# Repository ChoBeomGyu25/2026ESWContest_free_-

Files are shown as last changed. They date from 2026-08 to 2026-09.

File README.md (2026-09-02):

# 2026 ESWContest_free_옷개스트라

---

## 🏷️ Project Introduction

**옷개스트라**는 AI 기반 컴퓨터 비전과 듀얼 로봇팔을 활용하여 비정형 의류를 자동으로 인식하고 정리하는 **의류 자동 정리 로봇 시스템 「접신」**을 개발하고 있습니다.

일정한 형태를 유지하지 않는 의류의 특성을 고려하여 카메라 기반의 의류 인식과 상태 판단을 수행하고, 두 대의 로봇팔이 협업하여 의류를 파지하고 펼친 뒤 정렬 및 접기까지 수행하도록 시스템을 구성하였습니다.
이를 통해 사람이 직접 수행하던 반복적인 의류 정리 작업을 로봇과 인공지능을 이용하여 자동화하는 것을 목표로 합니다.

---

## 💡 Motivation
세탁은 **세탁기**, 건조는 **건조기**를 통해 자동화되고 있지만, 세탁이 끝난 의류를 **펼치고 정렬하여 접는 과정은 여전히 사람이 직접 수행해야 하는 대표적인 반복 가사 노동**으로 남아 있습니다. 특히 고령 인구와 맞벌이·1인 가구가 증가하면서 가사 노동에 대한 부담 역시 커지고 있으며, 반복적인 의류 정리는 시간적·신체적 부담과 일상생활의 비효율을 발생시킵니다.

기존에도 FoldiMate, Laundroid, Speedy-T 등 의류 정리를 위한 장치가 개발되었지만, **높은 가격, 긴 처리 시간, 반자동 방식, 제한적인 의류 대응 범위** 등의 한계가 존재합니다. 특히 사용자가 의류를 특정 형태로 투입하거나 사전에 정렬해야 하는 경우가 많아, 무작위로 놓이거나 구겨진 다양한 형태의 의류를 처음부터 끝까지 자동으로 처리하는 데에는 한계가 있습니다.

이에 저희는 비정형 상태로 놓인 의류를 AI기반 컴퓨터 비전으로 인식하고, 두 대의 로봇팔이 의류의 상태에 따라 직접 조작하여 **펼침·정렬·주름 및 접힘 보정·접기까지 전 과정을 수행하는 자동 의류 정리 로봇 시스템**을 제안합니다. 이를 통해 사용자의 의류 정리 부담을 줄이고, 기존 가전제품이 자동화하지 못했던 **세탁 이후의 의류 정리 과정까지 자동화**하는 것을 목표로 합니다.

---

## 🎯 Project Goal

본 프로젝트의 목표는 **무작위로 놓여 있거나 구겨진 의류의 상태를 로봇이 스스로 인식하고, 최종적으로 정돈된 형태까지 만드는 전 과정을 자동화하는 것**입니다.

의류의 형태와 위치를 AI 기반 컴퓨터 비전 통해 판단한 뒤, 두 대의 로봇팔이 협업하여 **의류 파지 → 배치 → 펼침 → 정렬 → 주름 및 접힘 보정 → 접기 → 완료 상태 판단**의 과정을 순차적으로 수행합니다.

특히 형태 변화가 큰 비정형 의류를 안정적으로 조작하기 위해 다양한 시각 인식 기술과 의류 상태에 따른 로봇 동작 판단 알고리즘을 결합하여, 여러 의류 상태에서도 유연하게 대응할 수 있는 자동 정리 시스템을 구현하는 것을 최종 목표로 합니다.

---

## 🤖 System Overview
스크린샷 2026-08-31 120610
스크린샷 2026-08-31 145607

본 시스템은 카메라 기반 비전 AI와 두 대의 로봇팔을 활용하여, 바구니에 무작위로 놓인 의류를 인식하고 펼침·정렬·보정·접기까지의 전 과정을 자동으로 수행합니다.

1. **RoArm이 바구니에서 의류를 파지**하여 폴딩 플레이트 위로 이동
2. **카메라 영상과 ArUco Marker / Checkerboard**를 이용하여 영상 좌표를 실제 로봇 작업 좌표계로 변환
3. **Segmentation 및 Pose 모델**을 통해 의류의 영역과 주요 특징점을 인식
4. 두 대의 로봇팔을 이용하여 **공중 Spread 및 초기 정렬 동작**을 수행
5. **Fallback Mask, Wrinkle Heatmap, UniDepth** 등을 이용하여 의류의 구김·접힘 및 현재 상태를 분석
6. 분석된 의류 상태를 기반으로 **펼침·당기기·회전 등 필요한 보정 동작**을 선택하여 반복 수행
7. 의류가 충분히 평활화되고 정렬되면 **Finish 상태로 판단**하고 폴딩 플레이트를 구동하여 의류를 접음
8. 접힌 의류를 배출한 뒤 로봇이 초기 위치로 복귀하여 **다음 의류 정리 작업을 준비**

---

## ⚙️ Hardware
스크린샷 2026-08-31 145738
Hardware 구성 및 기능
스크린샷 2026-08-31 145722

---

## 🧠 Software / AI
상의 주요 함수별 기능
하의 주요 함수별 기능
Jerber
Application

---

## 👕 Clothing Manipulation Process
스크린샷 2026-08-31 161525
스크린샷 2026-08-31 161535
스크린샷 2026-08-31 161541
스크린샷 2026-08-31 161547

---

## 📈Expected Effects & Development
스크린샷 2026-08-31 163309

본 시스템은 세탁 이후 사람이 직접 수행해야 했던 **의류 펼침·정렬·주름 및 접힘 보정·접기 과정을 자동화**함으로써 반복적인 가사 노동에 소요되는 시간과 신체적 부담을 줄이는 것을 목표로 합니다. 특히 일반적인 의류 정리에 평균 10~30분 정도가 소요되는 점을 고려할 때, 사용자의 개입을 최소화하여 의류 정리 과정을 자동으로 수행할 수 있다면 일상생활에서 실질적인 시간 절감 효과를 기대할 수 있습니다. 또한 자체 진행한 설문조사에서는 총 145명의 응답자 중 **111명, 약 76.6%가 '자동으로 옷을 개어주는 로봇'의 출시 시 구매 의향에 긍정적인 응답**을 보여, 자동 의류 정리에 대한 실제 사용자 수요와 활용 가능성도 확인하였습니다. 향후 세탁기와 건조기뿐만 아니라 의류 보관 시스템까지 연계한다면 **세탁 → 건조 → 정리 → 보관으로 이어지는 통합 스마트 홈 의류 관리 시스템**으로 발전할 수 있습니다.

본 기술은 가정용 스마트 홈을 넘어 **의류 유통·전자상거래 및 물류 산업으로의 확장 가능성**도 가지고 있습니다. 온라인 의류 판매 시장이 성장하면서 반품된 상품의 상태 확인, 펼침, 정렬, 재포장 등의 반복 작업 역시 증가하고 있으며, 이러한 과정에 비정형 의류 인식과 로봇 조작 기술을 적용하면 작업 효율과 공간 활용도를 높일 수 있습니다. 특히 다양한 형태로 놓인 의류를 AI 기반 컴퓨터 비전이 인식하고 상태에 따라 필요한 조작 동작을 선택하는 기술을 고도화할 경우, 패션 물류센터나 대형 세탁·정리 시설에서 반복적으로 수행되는 단순 작업을 자동화할 수 있습니다. 이를 통해 제한된 인력을 반복 작업에 투입하는 대신 **품질 관리, 고객 대응, 시스템 운영 등 보다 높은 부가가치를 갖는 업무에 집중**시킬 수 있으며, 장기적으로는 인력난 대응과 운영 비용 절감에도 기여할 수 있습니다. 최종적으로 본 프로젝트는 단순히 옷을 접는 하나의 가전제품을 넘어, **비정형 섬유 제품을 스스로 인식하고 판단하여 조작할 수 있는 지능형 로봇 자동화 플랫폼**으로 발전하는 것을 목표로 합니다.

---

## ⚙️ Environment

| Category | Environment |
|---|---|
| 💻 **Main Processor** |  |
| 🔧 **Sub Controller** |  |
| 🐧 **OS** |  |
| 📦 **Container** |  |
| 💻 **Programming Language** |  |
| 🤖 **Robot Platform** |   |
| 🔌 **Communication** |  |
| 📷 **Camera** |  |
| 📐 **Vision Calibration** |  |
| 🧠 **AI Framework** |   |
| 👕 **Garment Perception** |   |
| ⚡ **Inference Engine** |  |
| 🎮 **GPU Runtime** |  |
| 📏 **Depth Estimation** |  |
| 📊 **Learning / Prediction** |  |
| 🛠️ **Libraries & Tools** |    |

---

## 👥 Team Members

- 조범규
- 유채린
- 임혜강
- 정유환
- 조승진

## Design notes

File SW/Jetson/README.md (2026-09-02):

# Jetson 소프트웨어

이 디렉터리는 팀 **옷개스트라**의 자동 의류 정리 로봇 시스템 **「접신」**에서 NVIDIA Jetson Orin Nano를 기반으로 실행되는 **AI 기반 컴퓨터 비전, 의류 상태 분석, 조작 계획 및 듀얼 로봇팔 제어 소프트웨어**를 포함합니다.

Jetson은 상부 ELP OV2710 카메라 영상을 입력받아 의류의 위치와 형상을 인식하고, 카메라 픽셀 좌표를 실제 폴딩 보드 및 로봇 작업공간 좌표로 변환한 뒤 상의와 하의 상태에 맞는 조작 동작을 수행하는 핵심 연산 장치입니다.

현재 저장소에서는 실제 로봇에서 검증된 실행 코드와 학습 기반 동작 판단 모델을 함께 관리합니다.

---

# 1. 디렉터리 구성

    SW/Jetson/
    ├── README.md
    │
    ├── preprocessing/
    │   ├── README.md
    │   ├── upper/
    │   │   ├── README.md
    │   │   ├── run_upper.py
    │   │   └── ...
    │   │
    │   └── lower/
    │       ├── README.md
    │       ├── run_lower.py
    │       ├── dual/
    │       │   ├── step_e49_bottom_perception.py
    │       │   ├── step_e62_bottom_perception.py
    │       │   ├── step_d25_v2.py
    │       │   └── undistort/
    │       │       ├── bottom_vla-38_submission_full_auto.py
    │       │       ├── main-33_submission_runtime.py
    │       │       ├── 50-1.py
    │       │       ├── 54-3.py
    │       │       ├── 55-5.py
    │       │       ├── 58-3.py
    │       │       ├── 60-15.py
    │       │       ├── align-11.py
    │       │       └── ...
    │       └── outputs/
    │
    ├── common/
    │   ├── camera/
    │   └── calibration/
    │
    ├── models/
    │   ├── segmentation/
    │   └── pose/
    │       ├── upper/
    │       └── lower/
    │
    ├── policy/
    │
    └── runtime/

---

# 2. Jetson의 역할

Jetson 소프트웨어의 주요 기능은 다음과 같습니다.

1. ELP OV2710 카메라 영상 획득
2. 카메라 보정 및 렌즈 왜곡 보정
3. YOLO 기반 의류 세그멘테이션
4. 상의 / 하의 포즈 및 특징점 추론
5. 의류 마스크 및 윤곽선 분석
6. 키포인트 / 랜드마크 분석
7. 의류 방향 및 위치 분석
8. 접힘 / 주름 및 의류 형상 분석
9. 카메라 픽셀 좌표를 폴딩 보드 / 로봇 좌표로 변환
10. 로봇 파지점 계산
11. 조작 계획 생성
12. 듀얼 로봇팔 제어
13. 조작 후 새로운 의류 상태 재관찰
14. 학습 모델 기반 다음 조작 동작 결정
15. 접기 준비 완료 종료조건 판단
---

# 3. 전처리 및 실행 코드 (`preprocessing/`)

`preprocessing/`은 상의와 하의의 실제 의류 인식 및 로봇 조작 실행 코드를 관리합니다.

    SW/Jetson/preprocessing/
    ├── upper/
    └── lower/

상의와 하의는 구조와 조작 방법이 서로 다르기 때문에 각각 실제 로봇에서 검증된 실행 구조를 유지합니다.

단순한 소스 통합이나 중복 제거보다 **실제 로봇에서 검증된 의존성과 실행 재현성**을 우선합니다.

---

# 4. 현재 상의 실행 코드

현재 상의 메인 실행 코드는 GitHub 저장소에 포함되어 있습니다.

경로:

    SW/Jetson/preprocessing/upper/

실행 파일:

    SW/Jetson/preprocessing/upper/run_upper.py

현재 상의 시스템은 초기 의류 배치부터 **학습 모델 기반 동작 판단, 반복 조작 및 FINISH 판단까지 자동으로 수행하는 구조**로 구성되어 있습니다.

전체 흐름:

    바구니 의류 파지
            ↓
    폴딩 보드 위 이동
            ↓
    의류 내려놓기
            ↓
    YOLO 세그멘테이션 + YOLO 포즈
            ↓
    의류 상태 분석
            ↓
    커스텀 동작 결정 모델
            ↓
    안전한 조작 계획 생성
            ↓
    듀얼 로봇팔 동작 수행
            ↓
    Standby 복귀
            ↓
    새로운 의류 상태 재관찰
            ↓
    다음 동작 자동 판단
            ↓
    반복 조작 / FINISH

의존성 확인:

    python3 SW/Jetson/preprocessing/upper/run_upper.py --paths-only

실제 로봇 자동 실행:

    python3 SW/Jetson/preprocessing/upper/run_upper.py --physical-auto

`--physical-auto`는 실제 듀얼 로봇팔을 사용하는 상의 자동 정리 실행 옵션입니다.

---

# 5. 상의 학습 기반 자동 조작

상의에는 **현재 의류 상태를 보고 다음 조작 동작을 결정하는 커스텀 학습 모델**이 적용되어 있습니다.

의류 영상과 세그멘테이션, 포즈, 주름 및 위치 분석 결과를 이용하여 현재 상태를 표현하고, **Board+State v2 커스텀 모델**이 다음 동작을 우선 판단합니다. Jetson에서는 TensorRT 엔진으로 추론합니다.

현재 판단 구조:

    카메라 관찰
            ↓
    세그멘테이션 / 포즈 / 상태 분석
            ↓
    Board+State v2 모델
            ↓
    다음 조작 동작 후보 결정
            ↓
    신뢰도 및 적용 조건 확인
       /                    \
    통과                     미통과
     ↓                        ↓
    모델 판단 사용        규칙 기반 상태 판단 로직 사용
       \                    /
        ↓
    최종 조작 계획 및 안전 검사
            ↓
    로봇 실행
            ↓
    재관찰
            ↓
    다음 동작 자동 판단

현재 커스텀 모델은 7개 동작 클래스를 학습했으며, 제출용 실행 코드에서는 신뢰도와 margin 조건을 만족한 `CENTER`, `SPREAD`, `ROTATE`, `FINISH` 판단을 우선 직접 사용합니다. 그 외 경우에는 규칙 기반 상태 판단 로직으로 넘어갑니다.

즉, 현재 상의 코드는 **커스텀 모델을 우선 사용하여 동작을 판단하고, 모델 판단을 직접 채택하기 어려운 경우 규칙 기반 상태 판단 로직을 보조 경로로 사용**합니다.

실제 파지점과 이동 경로는 기존 검증된 조작 계획 및 안전 검사 로직을 통해 최종 결정됩니다.

조작이 끝나면 로봇팔이 대기 위치로 복귀한 뒤 새로운 영상을 다시 관찰하고 필요한 동작을 반복합니다. `FINISH`가 선택되면 해당 의류의 자동 조작 루프를 종료합니다.

---

# 6. 현재 하의 실행 코드

현재 하의 실행 코드는 **V38 Full-Auto 구조**로 구성되어 있으며 GitHub 저장소에 포함되어 있습니다.

실행 진입점:

    SW/Jetson/preprocessing/lower/run_lower.py

하의 Full-Auto 상위 실행 코드:

    SW/Jetson/preprocessing/lower/dual/undistort/bottom_vla-38_submission_full_auto.py

하위 실행 연결 코드:

    SW/Jetson/preprocessing/lower/dual/undistort/bottom_vla-23_submission_runtime.py
    SW/Jetson/preprocessing/lower/dual/undistort/main-33_submission_runtime.py

주요 인식 및 조작 관련 모듈:

    SW/Jetson/preprocessing/lower/dual/undistort/50-1.py
    SW/Jetson/preprocessing/lower/dual/undistort/54-3.py
    SW/Jetson/preprocessing/lower/dual/undistort/55-5.py
    SW/Jetson/preprocessing/lower/dual/undistort/58-3.py
    SW/Jetson/preprocessing/lower/dual/undistort/60-15.py
    SW/Jetson/preprocessing/lower/dual/undistort/align-11.py
    SW/Jetson/preprocessing/lower/dual/undistort/step_e49_bottom_perception.py
    SW/Jetson/preprocessing/lower/dual/undistort/step_e62_bottom_perception.py
    SW/Jetson/preprocessing/lower/dual/undistort/step_d25_v2.py

현재 하의는 카메라와 AI 모델을 이용하여 의류 상태를 인식한 뒤, 현재 상태에 맞는 의미 동작을 자동으로 선택하고 조작 후 다시 관찰하는 **반복형 자동 조작 구조**를 사용합니다.

주요 의미 동작:

- `BASKET_GRASP`
- `POSITION_ADJUST`
- `OUTER_PULL`
- `PRESS_SWEEP`
- `WAIST_PULL_LAYDOWN`
- `ALIGN`
- `FINISH`

하의 인식에는 의류 세그멘테이션, 하의 포즈, 마스크 기하 정보, 윤곽선, 허리선, 가랑이, 다리와 밑단, 접힘 및 주름, 정렬 상태 등의 정보를 함께 사용합니다.

---

# 7. 하의 자동 동작 판단

V38에서는 기존의 사용자 수동 동작 선택을 중심으로 한 구조에서 벗어나, 현재 관찰된 의류 상태를 기반으로 다음 의미 동작을 자동으로 선택합니다.

기본 판단 흐름:

    카메라 관찰
        ↓
    의류 세그멘테이션 / 하의 포즈 추론
        ↓
    의류 형상 및 상태 분석
        ↓
    AUTO-JUDGE
        ↓
    의미 동작 자동 선택
        ↓
    조작 계획 생성 및 안전 검사
        ↓
    로봇 조작

자동 판단 결과는 기존에 검증된 조작 코드와 연결되어 실제 파지점, 이동 경로 및 로봇 동작을 생성합니다.

즉 인식 및 상태 판단 계층과 실제 로봇 조작 계층을 분리하면서, 상위 자동 판단 결과를 기존 조작 코드에 전달하는 구조입니다.

---

# 8. 하의 Full-Auto 반복 조작 구조

V38 Full-Auto는 한 번의 상태 판단만 수행하는 것이 아니라 조작 후 새로운 상태를 다시 관찰하고 다음 동작을 판단하는 반복 구조를 사용합니다.

전체 흐름:

    X 입력으로 Full-Auto 시작
        ↓
    BASKET_GRASP
        ↓
    POSITION_ADJUST
        ↓
    새로운 의류 상태 관찰
        ↓
    AUTO-JUDGE
        ↓
    의미 동작 자동 선택
        ↓
    로봇 조작
        ↓
    새로운 의류 상태 재관찰
        ↓
    상태 재평가
        ↓
    다음 동작 자동 선택
        ↓
    반복 또는 FINISH

초기 바구니 파지 이후에는 의류를 작업 영역에 배치하고 위치를 보정한 뒤, 매 조작마다 새로운 카메라 관찰 결과를 이용하여 다음 동작을 다시 판단합니다.

이를 통해 이전 조작 이전의 상태를 계속 사용하는 것이 아니라 **조작 결과가 반영된 새로운 의류 상태를 기준으로 다음 행동을 결정**합니다.

---

# 9. 하의 종료조건 판단

하의 자동화는 단순히 정해진 횟수만큼 조작한 뒤 종료하는 방식이 아니라, 현재 의류 상태를 재평가하여 추가 조작이 필요한지 판단합니다.

상태 판단에는 다음과 같은 정보를 활용합니다.

- 의류가 충분히 펼쳐졌는지 여부
- 큰 접힘 및 주름 상태
- 허리선 구조
- 가랑이 및 다리 구조
- 양쪽 밑단 상태
- 의류 중심 위치
- 폴딩 보드 기준 정렬 상태
- 추가 위치 보정 또는 펼침 동작의 필요 여부

자동 판단 결과 추가 조작이 필요하면 다음 의미 동작을 선택하여 반복하고, 접기 단계로 진행할 수 있는 상태라고 판단하면 `FINISH`로 종료합니다.

반복 구조:

    의류 관찰
        ↓
    상태 분석
        ↓
    AUTO-JUDGE
        ↓
    추가 조작 필요?
       /          \
     YES          NO
      ↓            ↓
    동작 선택      FINISH
      ↓
    로봇 조작
      ↓
    재관찰
      ↓
    반복

---

# 10. 상의 / 하의 최종 통합 방향

상의와 하의는 모두 **의류를 관찰하고, 현재 상태를 판단하고, 필요한 동작을 수행한 뒤 다시 관찰하는 폐루프(Closed-loop) 구조**를 지향합니다.

    의류 입력
        ↓
    의류 인식
        ↓
    의류 상태 분석
        ↓
    동작 판단
        ↓
    두 로봇팔 조작
        ↓
    재관찰
        ↓
    상태 재평가
        ↓
    추가 동작 / 종료 판단
        ↓
    접기 준비 완료
        ↓
    폴딩 보드

상의는 Board+State v2 학습 모델과 규칙 기반 상태 판단을 결합한 자동 조작 모듈을 사용하며, 하의는 V38 Full-Auto 정책을 통해 의미 동작을 자동 선택하고 재관찰을 반복하는 구조를 사용합니다.

예선 제출에서는 상의와 하의의 각 실행 구조를 독립적으로 관리하며, 이후 전체 시스템에서는 의류 종류에 따라 해당 처리 흐름을 선택한 뒤 최종 폴딩 단계로 연결하는 구조를 목표로 합니다.

---

# 11. 모델

TensorRT 기반 AI 모델은 다음 디렉터리에서 관리합니다.

    SW/Jetson/models/

현재 의류 인식 모델:

    models/
    ├── segmentation/
    │   └── kfashion_yolo26s_seg3_e100_best.engine
    │
    └── pose/
        ├── upper/
        │   └── tshirt_pose_yolo26m_synth_artf_board_v1_best.engine
        │
        └── lower/
            └── bottom_pose8_yolo26m_robot_beige_retrain_all_v2.engine

상의에서는 의류 인식 모델과 별도로 **다음 조작 동작을 판단하기 위한 Board+State v2 커스텀 모델**을 사용합니다.

주요 파일:

    top_board_state_v2_fp32.engine
    state_normalization.npz

- `top_board_state_v2_fp32.engine` : Jetson에서 사용하는 TensorRT 동작 결정 모델
- `state_normalization.npz` : 모델 입력에 사용되는 상태값 정규화 정보

Jetson의 실제 동작 결정 추론에서는 TensorRT 엔진과 `state_normalization.npz`를 사용합니다.

자세한 내용:

    SW/Jetson/models/README.md
---

# 12. 공통 보정 리소스

`common/`은 카메라 좌표와 실제 폴딩 보드 / 로봇 작업공간을 연결하기 위한 카메라 및 보정 리소스를 포함합니다.

    SW/Jetson/common/
    ├── camera/
    └── calibration/

주요 리소스:

- ELP OV2710 카메라 왜곡 보정
- 카메라 내부 파라미터 보정
- 듀얼 로봇팔 / 폴딩 보드 설정
- 바구니 ARM2 Affine 보정
- 폴딩 보드 Homography

---

## Homography 주의사항

상의 공통 실행 코드와 하의 실행 코드에는 동일한 이름의 Homography 파일이 존재하지만 서로 다른 좌표계 처리 요구사항을 가집니다.

상의 / 공통:

    SW/Jetson/common/calibration/
    └── elp_ov2710_folding_board_homography_cache.json

하의 전용:

    SW/Jetson/preprocessing/lower/dual/undistort/
    └── elp_ov2710_folding_board_homography_cache.json

하의 버전은 원본 / 보정 프레임 기하 정보를 구분하기 위해 `H`, `raw_H`, `camera_geometry`, `schema_version` 정보를 사용합니다.

따라서 두 Homography 파일을 서로 덮어쓰거나 임의로 하나로 통합하면 안 됩니다.

자세한 내용:

    SW/Jetson/common/README.md
---

# 13. 동작 판단 정책

`policy/`는 의류 상태와 로봇 조작 동작 사이의 상위 판단 구조를 설명합니다.

### 상의

- YOLO 세그멘테이션 / 포즈 기반 의류 상태 인식
- Board+State v2 커스텀 모델 기반 동작 판단
- 학습 모델 판단을 우선 사용하고 필요한 경우 규칙 기반 상태 판단으로 보완
- 기존 조작 계획 및 안전 검사 로직을 이용하여 실제 로봇 동작 생성
- 조작 후 새로운 의류 상태를 재관찰
- 다음 동작을 다시 판단하는 반복 구조
- `FINISH` 판단 시 해당 의류의 자동 조작 종료

### 하의

- V38 Full-Auto 기반 자동 의미 동작 선택
- 바구니 파지 후 `POSITION_ADJUST`를 수행하여 작업 영역의 초기 상태 보정
- 카메라, 세그멘테이션, 하의 포즈 및 형상 분석 결과를 이용한 상태 판단
- `AUTO-JUDGE`를 통한 다음 의미 동작 자동 선택
- 선택된 동작을 기존 검증된 조작 코드와 연결
- 각 조작 이후 새로운 의류 상태를 재관찰
- 재관찰 결과를 이용하여 다음 동작을 반복 판단
- 접기 준비 상태가 충족되면 `FINISH`로 해당 의류 조작 종료

상의와 하의 모두 인식 결과를 한 번만 사용하는 방식이 아니라, **조작 → 재관찰 → 상태 재평가 → 다음 동작 판단**을 반복하는 폐루프 구조를 최종 동작 정책으로 사용합니다.

---

# 14. 실행 구조

「접신」의 실제 실행 구조는 **의류 인식 → 동작 판단 → 로봇 실행 → 재관찰 → 종료 판단**의 흐름으로 구성됩니다.

현재 실제 검증된 소스 코드는 다음 디렉터리에 위치합니다.

상의:

    SW/Jetson/preprocessing/upper/

하의:

    SW/Jetson/preprocessing/lower/

검증된 기존 소스 의존성과 동적 소스 로딩 구조를 유지하기 위해 실행 소스 자체를 `runtime/`로 임의 이동하지 않습니다.

`runtime/` 디렉터리는 전체 실행 구조와 상·하의 실행 관계를 설명하는 계층으로 사용합니다.

---

# 15. 실행 환경

현재 Jetson 실행 검증 환경:

- 주 프로세서: NVIDIA Jetson Orin Nano
- 운영체제: Ubuntu 22.04.3
- Python: 3.10.12
- TensorRT: 10.7.0
- OpenCV: 4.11.0
- NumPy: 1.26.4
- PyTorch: 2.10.0
- CUDA 런타임: 12.6 (PyTorch)
- Ultralytics: 8.4.45
- XGBoost: 3.2.0
- Docker: 29.7.2
- 로봇: Dual RoArm M2-S
- 카메라: ELP OV2710
- 카메라 해상도: 1280 × 720
- 통신: USB 시리얼

로봇 장치:

    ARM1: /dev/roarm_1
    ARM2: /dev/roarm_2

카메라 장치:

    /dev/video0

---

# 16. 최종 목표

Jetson 소프트웨어의 최종 목표는 다음과 같은 **폐루프 자동 의류 조작 시스템**을 구현하는 것입니다.

    카메라
      ↓
    의류 인식
      ↓
    의류 상태 분석
      ↓
    동작 판단
      ↓
    Dual RoArm 조작
      ↓
    재관찰
      ↓
    추가 동작 / 종료 판단
      ↓
    접기 준비 완료
      ↓
    폴딩 보드

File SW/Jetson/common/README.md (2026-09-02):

# 공통 리소스

이 디렉터리는 자동 의류 정리 로봇 시스템 **「접신」**의 Jetson 실행 환경에서 사용하는 공통 카메라 및 보정 리소스를 관리합니다.

카메라 영상에서 검출한 의류의 위치와 특징점을 실제 폴딩 보드 및 Dual RoArm M2-S 작업 좌표로 연결하기 위해 카메라 보정, Homography, Affine 변환 및 로봇 / 보드 설정을 사용합니다.

다만 실제 제출 실행 환경에서는 재현성과 기존 의존성 구조 보존을 위해 모든 파일을 상의와 하의가 동일한 위치에서 직접 참조하는 것은 아닙니다.

특히 하의 실행 코드는 일부 카메라 리소스와 하의 전용 Homography를 `preprocessing/lower/` 내부에 별도로 유지합니다.

---

# 1. 디렉터리 구성

    SW/Jetson/common/
    ├── README.md
    │
    ├── camera/
    │   ├── camera_undistort.py
    │   ├── elp_ov2710_1280x720_calibration.npz
    │   └── elp_ov2710_camera_controls.json
    │
    └── calibration/
        ├── dual_roarm_folding_board_config.json
        ├── basket_arm2_5point_affine.json
        └── elp_ov2710_folding_board_homography_cache.json

---

# 2. 카메라 리소스

## camera_undistort.py

경로:

    SW/Jetson/common/camera/camera_undistort.py

ELP OV2710 광각 카메라의 렌즈 왜곡을 보정하기 위한 공통 모듈입니다.

카메라 보정 정보를 이용하여 영상 왜곡을 보정하고, 이후 수행되는 세그멘테이션, 포즈 추론 및 기하 계산에서 픽셀 위치의 오차를 줄이는 데 사용합니다.

상의 제출 실행 코드에서는 해당 공통 카메라 모듈을 의존 파일로 사용합니다.

하의 실행 코드에는 동일한 카메라 보정 모듈의 검증된 로컬 복사본이 다음 위치에 존재합니다.

    SW/Jetson/preprocessing/lower/dual/undistort/
    └── camera_undistort.py

하의 로컬 복사본은 공통 버전과 파일 내용이 동일함을 SHA-256으로 검증했지만, 기존 하의 동적 소스 로딩 구조와 실행 재현성을 보존하기 위해 의도적으로 중복 유지합니다.

따라서 단순한 중복 제거를 목적으로 하의 로컬 복사본을 삭제하거나 import 구조를 변경하지 않는 것을 권장합니다.

---

## elp_ov2710_1280x720_calibration.npz

경로:

    SW/Jetson/common/camera/
    └── elp_ov2710_1280x720_calibration.npz

ELP OV2710 카메라의 1280 × 720 해상도 보정 데이터를 저장합니다.

카메라 내부 파라미터와 렌즈 왜곡 보정에 필요한 정보를 포함하며 `camera_undistort.py`와 함께 사용합니다.

현재 제출 실행 코드는 1280 × 720 카메라 입력을 기준으로 구성되어 있습니다.

하의 실행 코드에도 동일한 카메라 보정 NPZ의 검증된 로컬 복사본이 존재합니다.

    SW/Jetson/preprocessing/lower/dual/undistort/
    └── elp_ov2710_1280x720_calibration.npz

두 파일은 SHA-256 기준으로 동일하지만 하의 실행 코드의 검증된 소스 구조를 유지하기 위해 로컬 복사본을 보존합니다.

---

## elp_ov2710_camera_controls.json

경로:

    SW/Jetson/common/camera/
    └── elp_ov2710_camera_controls.json

ELP OV2710 카메라의 촬영 조건을 실행 환경에서 동일하게 재현하기 위한 **V4L2 카메라 제어 설정 파일**입니다.

이 파일은 카메라 내부 파라미터나 렌즈 왜곡 정보를 저장하는 보정 파일이 아니라, `/dev/video0`에 적용할 노출, 게인, 전원 주파수 및 화이트밸런스 값을 저장합니다.

현재 저장된 설정:

    auto_exposure: 1
    exposure_time_absolute: 151
    gain: 0
    power_line_frequency: 2
    white_balance_automatic: 0
    white_balance_temperature: 4600

상의 신규 자동화 실행기:

    SW/Jetson/preprocessing/upper/automation/run_upper_automation.py

는 실행 시 이 파일을 `--camera-controls-json` 인자로 전달합니다.

상의 자동화 코드에서는 카메라 초기화 과정에서 해당 설정을 `/dev/video0`에 적용한 뒤 카메라 보정, 세그멘테이션, 포즈 추론 및 의류 상태 판단을 수행합니다.

따라서 이 파일은 **카메라 영상의 밝기와 색 조건을 재현하여 비전 추론 환경을 일정하게 유지하기 위한 실행 의존 파일**입니다.

하의에도 동일한 카메라 설정의 검증된 로컬 복사본이 다음 위치에 존재합니다.

    SW/Jetson/preprocessing/lower/dual/
    └── elp_ov2710_camera_controls.json

공통 파일과 하의 로컬 파일은 SHA-256 기준으로 동일하지만, 하의 V38의 기존 실행 의존성 구조를 유지하기 위해 하의 로컬 복사본을 삭제하거나 공통 경로로 임의 통합하지 않습니다.

검증된 SHA-256:

    222e1b6826666a80918a271ea3c29dff62c77ecc94002dc4027a185e075bb206

---

# 3. 보정 리소스

## dual_roarm_folding_board_config.json

경로:

    SW/Jetson/common/calibration/
    └── dual_roarm_folding_board_config.json

Dual RoArm M2-S와 Folding Board 환경에서 사용하는 공통 Configuration입니다.

Robot Manipulation과 Board 기준 Geometry 계산에 필요한 설정 정보를 Runtime에서 참조합니다.

상의 및 하의 저장소 실행기에서 공통 보정 리소스로 사용합니다.

---

## basket_arm2_5point_affine.json

경로:

    SW/Jetson/common/calibration/
    └── basket_arm2_5point_affine.json

ARM2가 Basket 영역의 의류를 파지할 때 사용하는 Affine Calibration 데이터입니다.

Camera Image에서 얻은 Basket 영역의 Pixel Coordinate를 ARM2가 실제로 접근할 수 있는 Robot Workspace Coordinate로 변환하는 데 사용합니다.

개념적인 좌표 변환은 다음과 같습니다.

    Basket Camera Pixel
            ↓
    5-Point Affine Calibration
            ↓
    ARM2 Workspace Coordinate
            ↓
    Basket Grasp

상의 및 하의 실행 코드에서 저장소 상대경로 기반 공통 보정 리소스로 사용합니다.

---

# 4. 공통 Homography

경로:

    SW/Jetson/common/calibration/
    └── elp_ov2710_folding_board_homography_cache.json

이 파일은 Folding Board 영역의 Camera Pixel Coordinate와 실제 Board Coordinate 사이의 관계를 나타내는 Homography Calibration입니다.

현재 Common Directory의 Homography는 실제 상의 통합 Runtime에서 검증된 **H-only Calibration**입니다.

파일 특성:

    Size: 282 bytes
    JSON Key: H

검증된 SHA-256:

    282ebbcb635068031f0c238b7ab1b7c715819771ced86d614311ff875a13f397

상의 Runtime에서는 Segmentation 및 Pose Estimation으로 얻은 Pixel 위치를 실제 Folding Board 좌표로 변환하여 Robot Grasp Point 및 이동 Target을 계산하는 데 사용합니다.

---

# 5. 매우 중요: 하의 전용 Homography와의 차이

하의 Runtime에는 Common Homography와 **동일한 파일명을 가진 별도의 Homography**가 존재합니다.

하의 전용 경로:

    SW/Jetson/preprocessing/lower/dual/undistort/
    └── elp_ov2710_folding_board_homography_cache.json

이 파일은 Common Directory의 H-only Homography와 동일한 파일이 아닙니다.

---

## 공통 / 상의 Homography

경로:

    SW/Jetson/common/calibration/
    └── elp_ov2710_folding_board_homography_cache.json

특성:

    Size: 282 bytes
    Keys:
        H

SHA-256:

    282ebbcb635068031f0c238b7ab1b7c715819771ced86d614311ff875a13f397

---

## 하의 전용 Homography

경로:

    SW/Jetson/preprocessing/lower/dual/undistort/
    └── elp_ov2710_folding_board_homography_cache.json

특성:

    Size: 1040 bytes

    Keys:
        H
        raw_H
        camera_geometry
        schema_version

SHA-256:

    0a59a7a25f09af2edd235f5ee881ec48c9c52736200f7e91ed69ab1726b26a45

하의 `main-33_submission_runtime.py` Runtime은 Raw Frame과 Corrected Frame의 Geometry를 구분하여 처리하므로 `raw_H`와 `camera_geometry` 정보를 포함한 Lower 전용 Homography가 필요합니다.

---

## 절대 통합하지 않는 이유

두 Homography 파일은 파일명이 같지만 다음과 같이 Runtime 요구사항이 다릅니다.

    Common / Upper
        ↓
    H-only Geometry
        ↓
    상의 실행 코드

    Lower
        ↓
    H + raw_H + camera_geometry
        ↓
    Raw / Corrected Frame Geometry 분리
        ↓
    하의 실행 코드

따라서 다음 작업을 수행하면 안 됩니다.

- Lower Homography를 Common Homography 위에 덮어쓰기
- Common Homography를 Lower Homography 위에 덮어쓰기
- 파일명이 같다는 이유로 하나의 파일로 통합
- 하의 실행 코드가 공통 Homography 하나만 사용하도록 임의 수정
- 검증 없이 Homography JSON 구조 변경

**동일한 파일명은 동일한 Runtime Artifact라는 의미가 아닙니다.**

GitHub 제출본에서는 두 Calibration을 각각의 검증된 위치에 그대로 유지합니다.

---

# 6. 기본 좌표 변환 흐름

Folding Board 위 의류의 기본 좌표 변환은 다음과 같습니다.

    ELP OV2710 Camera
            ↓
    Camera Calibration
            ↓
    Lens Undistortion
            ↓
    Segmentation / Pose Estimation
            ↓
    Pixel Coordinate
            ↓
    Homography
            ↓
    Folding Board Coordinate
            ↓
    Robot Manipulation Target

Basket 영역에서는 별도의 Affine Calibration을 사용합니다.

    ELP OV2710 Camera
            ↓
    Basket Pixel Coordinate
            ↓
    basket_arm2_5point_affine.json
            ↓
    ARM2 Workspace Coordinate
            ↓
    Basket Grasp

---

# 7. Homography란?

Homography는 Camera Image Plane과 Folding Board와 같은 실제 평면 사이의 Projective Coordinate Relationship을 표현합니다.

Camera 영상에서 검출한 특정 Pixel을 Homography Matrix로 변환하여 Board 위 실제 위치에 대응시킴으로써 Vision Perception 결과를 Robot Manipulation 좌표와 연결합니다.

본 프로젝트에서는 Homography를 다음 작업에 활용합니다.

- Garment Grasp Point 좌표 변환
- Folding Board 기준 의류 위치 계산
- Robot 이동 Target 계산
- Garment Alignment
- Manipulation Planning
- Board Geometry 기준 Position Evaluation

---

# 8. Affine 보정

Basket 영역은 Folding Board와 다른 작업 공간에 존재하므로 별도의 ARM2 Affine Calibration을 사용합니다.

`basket_arm2_5point_affine.json`을 이용하여 Basket Camera Pixel Coordinate를 ARM2 Workspace Coordinate로 변환합니다.

이를 통해 Camera에서 인식한 Basket 내 의류 위치와 실제 ARM2 Grasp 위치를 연결합니다.

---

# 9. 실행 코드별 리소스 사용 구조

## 상의 실행 코드

주요 공통 의존 파일:

    SW/Jetson/common/camera/camera_undistort.py
    SW/Jetson/common/camera/elp_ov2710_1280x720_calibration.npz
    SW/Jetson/common/camera/elp_ov2710_camera_controls.json

    SW/Jetson/common/calibration/
    ├── dual_roarm_folding_board_config.json
    ├── basket_arm2_5point_affine.json
    └── elp_ov2710_folding_board_homography_cache.json

상의 기존 실행기:

    SW/Jetson/preprocessing/upper/run_upper.py

상의 신규 자동화 실행기:

    SW/Jetson/preprocessing/upper/automation/run_upper_automation.py

---

## 하의 실행 코드

하의 실행 코드는 일부 공통 보정 파일을 직접 사용합니다.

    SW/Jetson/common/calibration/
    ├── dual_roarm_folding_board_config.json
    └── basket_arm2_5point_affine.json

그러나 카메라 보정 모듈과 카메라 보정 데이터는 기존 하의 실행 의존성 구조를 보존하기 위해 로컬 복사본을 사용합니다.

    SW/Jetson/preprocessing/lower/dual/
    ├── elp_ov2710_camera_controls.json
    └── undistort/
        ├── camera_undistort.py
        └── elp_ov2710_1280x720_calibration.npz

Homography는 하의 전용 버전을 사용합니다.

    SW/Jetson/preprocessing/lower/dual/undistort/
    └── elp_ov2710_folding_board_homography_cache.json

하의 저장소 실행기:

    SW/Jetson/preprocessing/lower/run_lower.py

---

# 10. 보정 및 카메라 설정 파일 무결성 검증

GitHub 제출 과정에서는 실제 개발 및 로봇 실행 환경에서 사용한 보정 파일과 저장소 내부 파일이 동일한지 SHA-256으로 검증했습니다.

## camera_undistort.py

    4dcf2b0f74e2dff518184fca5a6910c2ec1813c109491b46502b6c06304cc348

## 카메라 보정 NPZ

    343cc5b96b2417603510938ae49ca29aed9265618b23fc6c57392d12439befa6

## ELP OV2710 카메라 제어 설정

    222e1b6826666a80918a271ea3c29dff62c77ecc94002dc4027a185e075bb206

## Dual RoArm / Folding Board Config

    807cc17db34cf48ba1e0eb7c770670a27e3370beee4c3d237659bfb6455c2373

## Basket ARM2 Affine

    546dc9c74cc629e407bad4967b9c94d267012e85bd0ef0d86ac5fe73a536d8d8

## 공통 / 상의 Homography

    282ebbcb635068031f0c238b7ab1b7c715819771ced86d614311ff875a13f397

## 하의 전용 Homography

    0a59a7a25f09af2edd235f5ee881ec48c9c52736200f7e91ed69ab1726b26a45

---

# 11. 공통 파일 관리 원칙

`common/`은 여러 실행 코드에서 직접 또는 저장소 실행기를 통해 재사용할 수 있는 보정 리소스를 관리합니다.

하지만 본 프로젝트에서는 **중복 제거보다 검증된 실행 환경의 재현성을 우선**합니다.

따라서 파일 내용이 동일하더라도 기존 하의 소스가 동일한 디렉터리 구조를 요구하는 경우에는 하의 로컬 복사본을 유지할 수 있습니다.

즉 다음 두 원칙을 동시에 적용합니다.

1. 안전하게 공유 가능한 보정 리소스는 `common/`에서 관리
2. 기존 실행 의존성 보존이 필요한 리소스는 검증된 로컬 복사본 유지

---

# 12. 보정 및 카메라 설정 변경 시 주의사항

보정 파일을 새로 생성하거나 교체하면 비전 좌표와 로봇 작업공간 좌표 사이의 관계가 달라질 수 있습니다.

따라서 다음 변경 후에는 전체 실행 환경을 다시 검증해야 합니다.

- 카메라 위치 변경
- 카메라 각도 변경
- 해상도 변경
- 폴딩 보드 위치 변경
- 로봇 베이스 위치 변경
- Homography 재생성
- 바구니 Affine 재생성
- 카메라 내부 파라미터 보정 변경
- `elp_ov2710_camera_controls.json`의 노출 / 게인 / 화이트밸런스 설정 변경

보정 파일은 실제 로봇 좌표 계산에 직접 연결되며, 카메라 제어 설정은 세그멘테이션과 포즈 추론에 입력되는 영상 조건에 영향을 줍니다.

따라서 단순한 파일 정리 목적으로 값을 변경하면 안 되며, 변경 시 카메라 영상과 비전 추론 결과를 다시 검증해야 합니다.

---

# 13. 요약

`common/` 디렉터리는 **「접신」**의 비전 인식 결과를 로봇 좌표로 연결하는 데 필요한 핵심 카메라 및 보정 리소스를 관리합니다.

주요 리소스:

- 카메라 왜곡 보정 모듈
- ELP OV2710 내부 파라미터 보정 파일
- ELP OV2710 카메라 제어 설정 파일
- Dual RoArm / 폴딩 보드 설정
- 바구니 ARM2 Affine 보정
- 공통 / 상의 폴딩 보드 Homography

하의 실행 코드는 일부 공용 보정 리소스를 재사용하면서도 검증된 동적 의존성 구조를 보존하기 위해 카메라 리소스와 하의 전용 Homography를 로컬 디렉터리에 유지합니다.

특히 **공통 / 상의 Homography와 하의 전용 Homography는 이름만 같고 내용과 실행 용도가 다르므로 절대로 서로 덮어쓰거나 통합해서는 안 됩니다.**

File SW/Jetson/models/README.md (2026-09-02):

# Models

이 디렉터리는 자동 의류 정리 로봇 시스템 **「접신」**의 Jetson Runtime에서 사용하는 AI 추론 모델을 관리합니다.

카메라 영상에서 의류 영역을 검출하기 위한 Segmentation 모델과 상의·하의의 주요 특징점을 검출하기 위한 Pose 모델을 사용합니다.

또한 상의 Runtime에서는 현재 의류 상태를 분석하여 다음 조작 동작을 결정하기 위해 별도로 학습한 동작 결정 모델을 사용합니다.

Jetson에서 사용하는 주요 추론 모델은 NVIDIA Jetson Orin Nano에서 빠르게 추론할 수 있도록 TensorRT Engine 형식으로 변환했습니다.

현재 Runtime에서는 다음 모델을 사용합니다.

- Garment Segmentation 모델
- 상의 Pose 모델
- 하의 Pose 모델
- 상의 동작 결정 모델

---

## 1. 디렉터리 구성

주요 Segmentation 및 Pose 모델의 디렉터리 구조는 다음과 같습니다.

    SW/Jetson/models/
    ├── README.md
    ├── segmentation/
    │   └── kfashion_yolo26s_seg3_e100_best.engine
    │
    └── pose/
        ├── upper/
        │   └── tshirt_pose_yolo26m_synth_artf_board_v1_best.engine
        │
        └── lower/
            └── bottom_pose8_yolo26m_robot_beige_retrain_all_v2.engine

상의와 하의는 동일한 Garment Segmentation 모델을 공유하며, 의류 구조의 차이를 반영하기 위해 Pose 모델은 각각 별도로 사용합니다.

상의 Runtime에서는 Segmentation 및 Pose 결과와 함께 현재 의류 상태를 입력으로 사용하는 별도의 동작 결정 모델을 사용합니다.

---

## 2. Segmentation Model

파일:

    SW/Jetson/models/segmentation/
    └── kfashion_yolo26s_seg3_e100_best.engine

카메라 영상에서 의류가 차지하는 영역을 픽셀 단위의 Mask로 검출하는 TensorRT 기반 Segmentation 모델입니다.

Segmentation 결과는 다음 정보 계산에 사용됩니다.

- 의류 전체 영역 검출
- Garment Mask 생성
- 의류 중심 위치 계산
- 외곽선 분석
- 의류 크기 및 형태 분석
- 파지 가능한 내부 영역 계산
- 의류 정렬 상태 분석
- Pose 결과와의 기하 관계 분석
- 주름 및 접힘 분석을 위한 유효 의류 영역 생성

검출된 Mask는 단순히 의류의 존재 여부를 판단하는 데 그치지 않고, 실제 로봇팔의 파지점 계산과 의류 형태 분석, 동작 계획 생성에도 사용됩니다.

본 Segmentation 모델은 상의와 하의 Runtime에서 공통으로 사용합니다.

---

## 3. 상의 Pose Model

파일:

    SW/Jetson/models/pose/upper/
    └── tshirt_pose_yolo26m_synth_artf_board_v1_best.engine

상의의 주요 구조를 나타내는 특징점을 검출하는 TensorRT 기반 Pose 모델입니다.

Pose 결과는 다음 작업에 사용됩니다.

- 상의 방향 판단
- 주요 특징점 검출
- 의류 형상 분석
- 파지점 후보 생성
- 최종 파지점 결정
- Segmentation Mask와의 기하 관계 분석
- 로봇팔 조작을 위한 기준점 생성

상의 Runtime에서는 Segmentation 결과와 Pose 특징점을 결합하여 현재 의류의 배치 상태를 분석하고, 두 로봇팔이 파지할 위치를 계산합니다.

Runtime 실행 파일:

    SW/Jetson/preprocessing/upper/run_upper.py

의존성 경로 확인:

    python3 SW/Jetson/preprocessing/upper/run_upper.py --paths-only

---

## 4. 상의 Action Decision Model

상의 자동 조작에서는 현재 의류 상태를 바탕으로 **다음에 수행할 조작 동작을 결정하기 위해 별도로 학습한 커스텀 모델**을 사용합니다.

주요 파일:

    top_board_state_v2_fp32.engine
    state_normalization.npz

`top_board_state_v2_fp32.engine`은 실제 Jetson Runtime에서 다음 동작을 판단하는 TensorRT 모델입니다.

`state_normalization.npz`는 모델에 입력되는 의류 상태값의 범위를 맞추기 위한 정규화 정보입니다.

모델은 크게 다음 두 종류의 정보를 입력으로 사용합니다.

- 폴딩보드 위의 현재 의류 영상
- Segmentation, Pose, 주름, 중심 위치 등에서 계산한 의류 상태값

의류 영상의 특징과 수치화된 상태 정보를 함께 분석하여 현재 상태에서 필요한 다음 조작을 판단합니다.

주요 판단 대상은 다음과 같습니다.

- `CENTER`
- `SPREAD`
- `LONG_PULL`
- `PRESS`
- `ROTATE`
- `ORTHO_SPREAD`
- `FINISH`

학습에는 PyTorch 기반의 **ResNet18 이미지 특징 추출부와 상태값을 처리하는 MLP를 결합한 분류 모델**을 사용했습니다.

학습이 완료된 모델은 다음 과정을 거쳐 Jetson에서 사용할 수 있는 TensorRT Engine으로 변환했습니다.

    PyTorch Model (.pt)
            ↓
    ONNX
            ↓
    TensorRT Engine
            ↓
    Jetson Runtime

현재 상의 Runtime은 **학습 모델과 기존 규칙 기반 상태 판단을 함께 사용하는 Hybrid 구조**로 구성했습니다.

모델의 신뢰도가 충분하고 실제 동작으로 연결할 수 있는 조건을 만족하면 학습 모델의 판단을 우선 사용합니다.

반대로 모델의 신뢰도가 부족하거나 안전 및 실행 조건을 만족하지 못하는 경우에는 기존 규칙 기반 상태 판단 로직을 사용합니다.

동작 결정 모델은 어떤 종류의 조작이 필요한지를 판단하는 역할을 담당하며, 실제 로봇의 파지점과 이동 경로를 직접 생성하지는 않습니다.

최종 파지점과 이동 경로는 각 동작별로 실제 로봇에서 검증된 조작 계획 및 안전 검사 로직을 통해 계산합니다.

---

## 5. 하의 Pose Model

파일:

    SW/Jetson/models/pose/lower/
    └── bottom_pose8_yolo26m_robot_beige_retrain_all_v2.engine

하의 의류의 주요 특징점을 추론하기 위한 TensorRT 기반 Pose 모델입니다.

본 모델은 허리, 가랑이, 양쪽 밑단의 주요 위치를 검출하며, 검출된 Pose 결과는 하의의 형태와 방향을 분석하고 실제 로봇 동작을 계획하는 데 사용됩니다.

하의 Pose 결과는 다음 분석 및 동작 계획에 활용됩니다.

- 허리선 구조 분석
- 가랑이 위치 분석
- 양쪽 다리 구조 분석
- 밑단 영역 판단
- 하의 방향 추정
- 의류 중심축 분석
- Segmentation Mask와의 결합
- 접힘 및 좌우 비대칭 분석
- 로봇 파지 후보 생성
- `PRESS_SWEEP` 동작 계획
- `WAIST_PULL_LAYDOWN` 동작 계획
- `ALIGN` 정렬 계획
- `FINISH` 상태 평가에 필요한 구조 정보 제공

하의 Runtime에서는 Pose 결과를 Segmentation Mask, 주름 정보 및 의류 형태 분석 결과와 결합하여 현재 하의의 위치, 방향, 펼쳐진 정도와 추가 조작 필요 여부를 판단합니다.

주요 인식 모듈:

    SW/Jetson/preprocessing/lower/dual/undistort/
    ├── step_e49_bottom_perception.py
    ├── step_e62_bottom_perception.py
    └── step_d25_v2.py

Runtime 실행 파일:

    SW/Jetson/preprocessing/lower/run_lower.py

의존성 경로 확인:

    python3 SW/Jetson/preprocessing/lower/run_lower.py --paths-only

---

## 6. 모델 사용 흐름

전체적인 의류 인식 과정은 다음과 같습니다.

    ELP OV2710 Camera
            ↓
    카메라 보정 및 왜곡 보정
            ↓
    의류 Segmentation
            ↓
    의류 Mask 생성
            ↓
    상의 또는 하의 Pose 추론
            ↓
    Mask + Pose + 의류 형태 분석
            ↓
    특징점 및 파지 후보 계산
            ↓
    보정 정보를 이용한 로봇 좌표 변환
            ↓
    두 로봇팔 조작

상의와 하의는 공통 Segmentation 모델을 사용하지만, 의류의 구조와 조작 방식이 다르기 때문에 Pose 모델과 이후 상태 판단 및 동작 계획은 각각 별도로 구성했습니다.

### 상의 자동 조작 흐름

상의의 경우 의류 인식 이후 별도로 학습한 동작 결정 모델을 이용하여 다음 Action을 판단합니다.

    현재 의류 영상
            +
    Segmentation / Pose / 주름 / 위치 기반 상태값
            ↓
    상의 Action Decision Model
            ↓
    다음 Action 결정
            ↓
    동작 계획 생성
            ↓
    두 로봇팔 조작
            ↓
    새 영상 재관찰
            ↓
    다음 Action 판단 / FINISH

동작 결정 모델은 다음에 어떤 조작이 필요한지를 선택하며, 실제 파지 위치와 로봇 이동 경로는 각 Action Runtime에서 계산합니다.

### 하의 자동 조작 흐름

하의 Runtime은 바구니에서 의류를 가져오는 `BASKET_GRASP`부터 시작하여, 의류의 초기 위치를 보정하는 `POSITION_ADJUST`를 1회 수행한 뒤 현재 상태를 자동으로 분석합니다.

    X 입력
            ↓
    BASKET_GRASP
            ↓
    POSITION_ADJUST
            ↓
    새 영상 획득
            ↓
    Segmentation + Pose 추론
            ↓
    형태 / 주름 / 접힘 / 정렬 상태 분석
            ↓
    현재 하의 상태 판단
            ↓
    다음 Action 자동 결정
            ↓
    고정 동작 계획(Frozen Plan) 생성
            ↓
    두 로봇팔 조작
            ↓
    새 영상 재관찰
            ↓
    상태 재평가
            ↓
    다음 Action 판단 / FINISH

현재 하의 Runtime에서 사용하는 주요 Action은 다음과 같습니다.

- `BASKET_GRASP`
- `POSITION_ADJUST`
- `OUTER_PULL`
- `PRESS_SWEEP`
- `WAIST_PULL_LAYDOWN`
- `ALIGN`
- `FINISH`
- `REJUDGE`

`BASKET_GRASP`는 바구니에서 의류를 파지하여 폴딩보드 위로 가져오는 초기 동작이며, `POSITION_ADJUST`는 이후 자동 정리를 시작하기 전에 의류의 초기 위치를 보정하는 동작입니다.

`REJUDGE`는 실제 로봇 조작을 수행하는 Action이 아니라, 새로운 카메라 영상을 획득하여 현재 의류 상태와 다음 Action을 다시 판단하는 제어 Action입니다.

한 번의 카메라 관찰에서 파지점, 목표점 및 이동 경로가 계산되면 해당 결과를 **Frozen Plan**으로 고정합니다.

각 로봇 동작이 끝난 뒤에는 새로운 카메라 영상을 획득하여 변화된 의류 상태를 다시 분석하고 다음 Action을 결정합니다.

---

## 7. Runtime 연동

### 상의

Runtime 실행 파일:

    SW/Jetson/preprocessing/upper/run_upper.py

Segmentation 모델:

    SW/Jetson/models/segmentation/kfashion_yolo26s_seg3_e100_best.engine

상의 Pose 모델:

    SW/Jetson/models/pose/upper/tshirt_pose_yolo26m_synth_artf_board_v1_best.engine

상의 Action Decision Model:

    top_board_state_v2_fp32.engine
    state_normalization.npz

상의 Runtime은 Segmentation 및 Pose 결과를 이용하여 현재 의류 상태를 분석하고, 커스텀 학습 모델을 통해 다음 조작 동작을 판단합니다.

모델의 판단 결과는 기존 규칙 기반 상태 판단 및 안전 검사 로직과 함께 사용됩니다.

동작 결정 이후 실제 파지점과 이동 경로는 각 Action의 기존 조작 계획 및 안전 검사 로직을 이용하여 계산합니다.

---

### 하의

Runtime 실행 파일:

    SW/Jetson/preprocessing/lower/run_lower.py

Segmentation 모델:

    SW/Jetson/models/segmentation/kfashion_yolo26s_seg3_e100_best.engine

하의 Pose 모델:

    SW/Jetson/models/pose/lower/bottom_pose8_yolo26m_robot_beige_retrain_all_v2.engine

`run_lower.py`는 GitHub Repository 내부 경로를 기준으로 하의 Runtime에 필요한 모델과 카메라·로봇 보정 파일의 경로를 전달합니다.

현재 하의 Runtime은 Segmentation 및 Pose 결과와 의류의 형태, 주름, 접힘 및 정렬 상태를 함께 분석하여 현재 상태에 필요한 다음 Action을 결정합니다.

주요 Action은 다음과 같습니다.

- `BASKET_GRASP`
- `POSITION_ADJUST`
- `OUTER_PULL`
- `PRESS_SWEEP`
- `WAIST_PULL_LAYDOWN`
- `ALIGN`
- `FINISH`
- `REJUDGE`

`REJUDGE`는 로봇을 직접 움직이는 동작이 아니라, 새로운 카메라 영상을 획득하여 현재 의류 상태와 다음 Action을 다시 판단하기 위한 제어 Action입니다.

한 번의 카메라 관찰에서 생성한 파지점, 목표점 및 이동 경로는 고정 동작 계획(Frozen Plan)으로 유지한 뒤 실제 로봇 동작에 사용합니다.

각 동작이 끝난 뒤에는 새로운 카메라 영상을 획득하고 변화된 의류 상태를 다시 분석하여 다음 Action을 결정합니다.

이를 통해 하의 Runtime은 **인식 → 상태 판단 → Action 결정 → 로봇 조작 → 재관찰 → 상태 재평가**가 반복되는 구조로 동작합니다.

---

## 8. 검증 환경

현재 TensorRT Engine을 사용하는 Jetson Runtime의 개발 및 검증 환경은 다음과 같습니다.

- NVIDIA Jetson Orin Nano
- Ubuntu 22.04.3
- Python 3.10.12
- TensorRT 10.7.0
- OpenCV 4.11.0
- PyTorch 2.10.0
- PyTorch CUDA 12.6
- NumPy 1.26.4
- Ultralytics 8.4.45
- XGBoost 3.2.0
- Docker 29.7.2

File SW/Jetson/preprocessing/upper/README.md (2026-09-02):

# 상의 의류 조작 Runtime

이 디렉터리는 팀 **옷개스트라**의 자동 의류 정리 로봇 시스템 **「접신」**에서 사용하는 상의 의류 조작용 Jetson 실행 코드를 포함합니다.

현재 상의 시스템은 두 단계로 구성되어 있습니다.

1. `run_upper.py`를 이용한 바구니 파지, Folding Board 배치 및 초기 정렬
2. `upper.py`를 이용한 학습 모델 기반 반복 의류 조작 및 종료 판단

현재는 두 실행 코드를 분리하여 사용하고 있으며, 추후 하나의 상의 통합 실행 코드로 연결할 예정입니다.

---

## 1. 개요

상의 시스템은 두 대의 로봇팔과 상부 ELP OV2710 카메라를 이용하여 의류를 인식하고, 파지·이동·정렬한 뒤 Folding이 가능한 상태까지 자동으로 조작합니다.

전체 동작 흐름은 다음과 같습니다.

    바구니의 상의 파지
            ↓
    Folding Board 위로 이동
            ↓
    의류 배치 및 초기 정렬
            ↓
    Segmentation / 상의 Pose 추론
            ↓
    초기 파지점 계산
            ↓
    두 로봇팔 파지
            ↓
    공중 정렬 및 Laydown
            ↓
    상의 자동 조작 코드 실행
            ↓
    현재 의류 상태 재관찰
            ↓
    학습 모델 기반 다음 동작 판단
            ↓
    필요한 조작 수행
            ↓
    재관찰 및 다음 동작 판단
            ↓
    FINISH

첫 번째 단계에서는 의류를 바구니에서 꺼내 Folding Board 위에 안정적으로 배치합니다.

두 번째 단계에서는 배치된 의류의 상태를 반복적으로 관찰하면서 필요한 조작을 자동으로 수행합니다.

---

## 2. 실행 구조

### 1단계: 상의 전처리 및 초기 배치

현재 상의 전처리 실행은 `run_upper.py`를 사용합니다.

실제 로봇 실행:

    python3 run_upper.py --physical-auto

`run_upper.py`는 다음 과정을 수행합니다.

1. 로봇팔이 바구니에서 의류 파지
2. Folding Board 위로 의류 이동
3. 의류 배치
4. Segmentation 및 상의 Pose 추론
5. 의류 형상과 Keypoint 분석
6. 최종 파지점 계산
7. 두 로봇팔이 의류 파지
8. 공중 상승 및 위치 정렬
9. Laydown
10. 로봇팔 대기 위치 복귀

---

### 2단계: 상의 자동 의류 조작

`run_upper.py`의 초기 배치 과정이 끝난 뒤에는 별도의 상의 자동 조작 코드인

    upper.py

를 실행합니다.

`upper.py`는 Folding Board 위에 놓인 상의를 다시 관찰하고, 현재 상태에 필요한 조작을 자동으로 결정하여 수행합니다.

기본 흐름:

    Camera Observation
            ↓
    Segmentation / Pose
            ↓
    의류 상태 분석
            ↓
    커스텀 학습 모델
            ↓
    다음 조작 동작 결정
            ↓
    파지점 및 이동 경로 계산
            ↓
    안전 조건 검사
            ↓
    로봇팔 조작
            ↓
    Standby 복귀
            ↓
    새로운 상태 재관찰
            ↓
    다음 동작 판단

이 과정을 반복하며 추가 조작이 필요하지 않은 상태에서는 `FINISH`를 판단하여 해당 의류의 자동 조작을 종료합니다.

현재 `run_upper.py`와 `upper.py`는 각각 검증된 기능을 유지하기 위해 분리되어 있으며, 추후 **초기 배치부터 반복 자동 조작 및 FINISH까지 하나의 실행 흐름으로 동작하도록 통합할 예정**입니다.

---

## 3. 상의 자동 동작 판단

상의 자동 조작에는 현재 의류 상태를 바탕으로 다음 동작을 결정하기 위해 직접 학습한 **커스텀 동작 결정 모델**을 사용합니다.

모델은 다음 정보를 함께 사용합니다.

- Folding Board 위의 현재 의류 영상
- Segmentation 결과
- 상의 Pose 결과
- 의류 중심 위치
- Mask 형상 및 크기
- Solidity
- 의류 방향
- 주름 및 CCA 분석 결과
- 기타 의류 상태값

학습 모델은 현재 상태에서 필요한 조작 동작을 분류합니다.

주요 동작:

- `CENTER`
- `SPREAD`
- `LONG_PULL`
- `PRESS`
- `ROTATE`
- `ORTHO_SPREAD`
- `FINISH`

현재 상의 자동 조작에서는 **커스텀 학습 모델의 판단을 우선 사용**합니다.

모델의 신뢰도가 부족하거나 적용 조건을 만족하지 못하는 경우에는 기존 **규칙 기반 상태 판단 로직**을 이용하여 동작을 결정합니다.

학습 모델은 어떤 동작이 필요한지를 판단하며, 실제 로봇의 파지점과 이동 경로는 기존에 검증된 조작 계획 및 안전 검사 로직에서 계산합니다.

---

## 4. 실행 방법

### 상의 전처리 및 초기 배치

실제 로봇 동작:

    python3 run_upper.py --physical-auto

### 파일 경로 확인

카메라와 로봇을 실제로 동작시키지 않고 필요한 파일의 경로와 존재 여부를 확인합니다.

    python3 run_upper.py --paths-only

### Source Merge 구조 확인

    python3 run_upper.py --merge-self-test

`run_upper.py`는 GitHub 저장소 내부의 상대경로를 기준으로 모델, 카메라 보정 파일, Homography, 로봇 보정 파일 및 실행 소스의 위치를 계산합니다.

이를 통해 기존 로봇에서 검증된 핵심 코드의 구조를 크게 변경하지 않고 GitHub 저장소에서도 실행할 수 있도록 구성했습니다.

---

## 5. 주요 실행 파일

### 상의 전처리 및 초기 배치

- `run_upper.py`
  - 상의 초기 실행 진입점
  - 필요한 파일 경로 확인 및 실제 상의 전처리 과정 실행

### 기존 상의 통합 코드

- `d50_v14_fix11_basket_frontend_fix111_second_grasp_open_statefix.py`
  - 바구니 파지부터 Folding Board 배치, 로봇팔 조작까지 수행하는 기존 상의 통합 코드

### 기반 코드

- `basket_hover_torque_auto_grasp_dual_handoff_v25_fix11_raw_preview_post_mask_v8.py`
  - 바구니 파지, 보드 배치 및 로봇팔 조작 기능 제공

- `d50_v13.py`
  - 의류 인식, 형상 분석 및 조작에 필요한 주요 기능 제공

### 상의 자동 조작 코드

- `upper.py`
  - Folding Board 위에 배치된 상의를 반복 관찰
  - 커스텀 학습 모델을 이용한 다음 동작 판단
  - 규칙 기반 판단 보조
  - 파지점 및 이동 경로 계산
  - 로봇팔 조작
  - 조작 후 재관찰
  - `FINISH`까지 자동 반복

### 보조 모듈

- `step_d25_v2.py`
- `step_e49_bottom_perception.py`
- `step_e62_bottom_perception.py`

일부 보조 모듈은 개발 과정에서 사용한 기존 파일명을 그대로 유지하고 있습니다.

`step_e49_bottom_perception.py`, `step_e62_bottom_perception.py`와 같은 파일은 현재 상의 실행 코드의 의존성으로 사용되며, 호환성을 유지하기 위해 파일명을 변경하지 않았습니다.

---

## 6. 공통 의존 파일

상의와 하의에서 공통으로 사용하는 파일은 중복 저장하지 않고 `SW/Jetson/common`과 `SW/Jetson/models` 디렉터리에 배치되었습니다.

### Camera

- `SW/Jetson/common/camera/camera_undistort.py`
- `SW/Jetson/common/camera/elp_ov2710_1280x720_calibration.npz`

### Calibration

- `SW/Jetson/common/calibration/dual_roarm_folding_board_config.json`
- `SW/Jetson/common/calibration/basket_arm2_5point_affine.json`
- `SW/Jetson/common/calibration/elp_ov2710_folding_board_homography_cache.json`

### 의류 인식 모델

- `SW/Jetson/models/segmentation/kfashion_yolo26s_seg3_e100_best.engine`
- `SW/Jetson/models/pose/upper/tshirt_pose_yolo26m_synth_artf_board_v1_best.engine`

### 상의 동작 결정 모델

상의 자동 조작 코드에서는 별도의 커스텀 학습 모델을 사용합니다.

주요 파일:

    top_board_state_v2_fp32.engine
    state_normalization.npz

- `top_board_state_v2_fp32.engine`
  - 현재 의류 상태에서 필요한 다음 조작 동작을 판단하는 TensorRT 모델

- `state_normalization.npz`
  - 모델 입력으로 사용하는 상태값의 정규화 정보

학습 원본과 모델 변환 과정에서는 `.pt`와 `.onnx` 파일을 사용했으며, Jetson에서 실제 추론할 때는 TensorRT Engine과 상태 정규화 파일을 사용합니다.

Homography는 실제 상의 실행 코드에서 검증된 Calibration 파일을 사용합니다.

---

## 7. 상의 자동화 구조

현재 상의 자동화는 **초기 배치를 담당하는 전처리 코드와 반복 의류 조작을 담당하는 자동화 코드를 연속적으로 동작시키는 구조**입니다.

현재는 개발 및 검증 과정에서 두 코드를 분리하여 관리하고 있으며, 추후 다음과 같이 하나의 통합 실행 구조로 구성할 예정입니다.

    run_upper.py
        ↓
    바구니 파지
        ↓
    Folding Board 배치
        ↓
    초기 의류 인식 및 정렬
        ↓
    Laydown
        ↓
    upper.py
        ↓
    현재 의류 상태 관찰
        ↓
    학습 모델 기반 동작 판단
        ↓
    필요한 조작 수행
        ↓
    재관찰
        ↓
    다음 동작 판단
        ↓
    FINISH

---

## 8. Runtime 환경

- NVIDIA Jetson Orin Nano
- Ubuntu 22.04.3
- Python 3.10.12
- TensorRT 10.7.0
- OpenCV 4.11.0
- NumPy 1.26.4
- Ultralytics 8.4.45
- Dual RoArm M2-S
- ELP OV2710 Camera
- ARM1 Serial Port: `/dev/roarm_1`
- ARM2 Serial Port: `/dev/roarm_2`
- Camera Device: `/dev/video0`

---

## 9. Runtime Manifest

`UPPER_RUNTIME_MANIFEST.json`에는 제출용 상의 실행에 필요한 주요 파일과 각 파일의 SHA-256 해시값이 기록되어 있습니다.

---

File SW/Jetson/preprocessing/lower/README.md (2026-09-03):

# 하의 의류 Full-Auto Manipulation Runtime

본 디렉터리는 **2026 임베디드 소프트웨어 경진대회 자유공모** 출품작  
**옷개스트라 - 접신** 프로젝트의 Jetson 기반 **하의 인식·판단·조작 Runtime**을 포함합니다.

현재 하의 Runtime의 최종 실행 파일은 `bottom_vla-38_submission_full_auto.py`입니다.

카메라 영상으로부터 하의 상태를 반복적으로 관찰하고, 현재 상태에 적합한 동작을 자동으로 선택하여 하의가 접을 수 있는 상태가 될 때까지 로봇 조작을 반복합니다.

초기 Runtime은 사용자가 다음 동작을 직접 선택하는 방식이었으며, 현재 V38 Runtime에서는 의류 상태 분석부터 다음 동작 선택까지 자동으로 수행합니다.

---

## 1. 전체 실행 구조

현재 하의 Runtime의 핵심 흐름은 다음과 같습니다.

```text
카메라 영상 입력
    ↓
의류 영역 분할
    ↓
하의 특징점 / 형태 / 주름 / 접힘 분석
    ↓
현재 의류 상태 판단
    ↓
다음 동작 자동 결정
    ↓
고정 동작 계획(Frozen Plan) 생성
    ↓
로봇 동작 실행
    ↓
새 영상 재관찰
    ↓
다음 Action 자동 결정
    ↓
FINISH
```

V38은 한 번의 동작만 수행하고 종료되는 구조가 아닙니다.

각 로봇 동작이 끝난 뒤 카메라 영상을 새로 획득하고, 변화된 하의 상태를 다시 분석하여 다음에 필요한 동작을 자동으로 결정합니다.

이 과정을 반복하여 하의가 접을 수 있는 상태에 도달했다고 판단되면 `FINISH` 상태로 종료합니다.

---

## 2. Runtime 실행 파일

GitHub Repository에서는 다음 파일을 통해 하의 Runtime을 실행합니다.

```text
SW/Jetson/preprocessing/lower/run_lower.py
```

실제 완전 자동 Runtime 실행 파일은 다음과 같습니다.

```text
SW/Jetson/preprocessing/lower/dual/undistort/
└── bottom_vla-38_submission_full_auto.py
```

전체 Runtime 연결 구조는 다음과 같습니다.

```text
run_lower.py
    ↓
bottom_vla-38_submission_full_auto.py
    ↓
bottom_vla-23_submission_runtime.py
    ↓
main-33_submission_runtime.py
```

`run_lower.py`는 현재 GitHub Repository의 위치를 기준으로 필요한 Runtime 소스, AI 모델, 카메라 보정 파일 및 로봇 보정 파일의 경로를 계산하여 하위 Runtime에 전달합니다.

이를 통해 개발 과정에서 사용했던 `/workspace/project_train/...` 형태의 절대경로에 직접 의존하지 않고, GitHub Repository 내부의 파일을 이용하여 실행할 수 있도록 구성했습니다.

---

## 3. 하의 Runtime 디렉터리 구조

현재 완전 자동 하의 Runtime의 주요 구조는 다음과 같습니다.

```text
lower/
├── README.md
├── run_lower.py
├── outputs/
│
└── dual/
    ├── elp_ov2710_camera_controls.json
    │
    └── undistort/
        ├── bottom_vla-38_submission_full_auto.py
        ├── bottom_vla-23_submission_runtime.py
        ├── main-33_submission_runtime.py
        │
        ├── 50-1.py
        ├── 54-3.py
        ├── 55-5.py
        ├── 58-3.py
        ├── 60-15.py
        ├── align-11.py
        │
        ├── step_e49_bottom_perception.py
        ├── step_e62_bottom_perception.py
        ├── step_d25_v2.py
        │
        ├── camera_undistort.py
        └── elp_ov2710_folding_board_homography_cache.json
```

하의 Pose 모델은 다음 경로를 사용합니다.

```text
SW/Jetson/models/pose/lower/
└── bottom_pose8_yolo26m_robot_beige_retrain_all_v2.engine
```

상의와 하의에서 공통으로 사용하는 Garment Segmentation Model은 다음 경로를 사용합니다.

```text
SW/Jetson/models/segmentation/
└── kfashion_yolo26s_seg3_e100_best.engine
```

---

## 4. Full-Auto Controller

### bottom_vla-38_submission_full_auto.py

V38은 현재 하의 Runtime의 최상위 Full-Auto Controller입니다.

주요 역할은 다음과 같습니다.

* 완전 자동 작업 시작 및 종료 관리
* 새로운 카메라 영상 획득
* 현재 의류 상태 재판단
* 다음 동작 자동 선택
* 고정 동작 계획(Frozen Plan) 생성 및 실행 관리
* Action 완료 후 다음 영상 재관찰
* `FINISH` 상태 관리
* Runtime 소스 무결성 확인
* 실제 실행 전 안전 조건 확인

개념적인 실행 흐름은 다음과 같습니다.

```text
BASKET_GRASP
    ↓
POSITION_ADJUST
    ↓
새 영상 획득
    ↓
자동 상태 판단
    ↓
필요한 조작 동작 실행
    ↓
새 영상 획득
    ↓
자동 상태 판단
    ↓
...
    ↓
FINISH
```

초기 `BASKET_GRASP`로 바구니에서 의류를 가져온 뒤에는 `POSITION_ADJUST`를 한 번 수행합니다.

이후부터는 카메라로 하의 상태를 반복적으로 관찰하면서 현재 상태에 필요한 동작을 자동으로 선택합니다.

---

## 5. Full-Auto Runtime 기반 코드

### bottom_vla-23_submission_runtime.py

V38이 사용하는 Full-Auto Runtime 기반 코드입니다.

주요 역할은 다음과 같습니다.

* Main Runtime 소스 탐색
* 각 동작 소스 탐색
* 바구니 보정 파일 탐색
* 동작 종류와 실제 조작 Runtime 연결
* 고정 동작 계획 관리
* 각 동작 Runtime 연결
* 동작 실행 결과 처리
* 자동 동작 준비 및 실행 구조 제공

현재 주요 동작 연결 관계는 다음과 같습니다.

| 동작 종류 | Runtime |
| --- | --- |
| `BASKET_GRASP` | 바구니 파지 Runtime |
| `POSITION_ADJUST` | `58-3.py` |
| `OUTER_PULL` | `54-3.py` |
| `PRESS_SWEEP` | `55-5.py` |
| `WAIST_PULL_LAYDOWN` | `60-15.py` |
| `ALIGN` | `align-11.py` |
| `FINISH` | 작업 종료 상태 |

---

## 6. Main Runtime

### main-33_submission_runtime.py

하의 완전 자동 시스템의 공통 Runtime 기능을 담당합니다.

주요 역할은 다음과 같습니다.

* 카메라 초기화
* 카메라 설정 적용
* 원본 영상 관리
* 왜곡 보정 영상 관리
* TensorRT 의류 영역 분할 모델 불러오기
* TensorRT 하의 Pose 모델 불러오기
* 카메라 보정값 불러오기
* Homography 불러오기
* 로봇 및 폴딩보드 설정 불러오기
* 각 동작 Runtime 소스 동적 연결
* 소스 SHA-256 무결성 확인
* 두 대의 Robot Arm Runtime 관리

V38 / V23 Runtime에서는 다음 동작 소스를 사용합니다.

```text
D50 → 50-1.py
D54 → 54-3.py
D55 → 55-5.py
D58 → 58-3.py
D56 Slot → 60-15.py
ALIGN → align-11.py
```

특히 `60-15.py`는 Main Runtime의 D56 연결 위치에 적용되어 `WAIST_PULL_LAYDOWN` 동작을 담당합니다.

---

## 7. 주요 동작 모듈

### 50-1.py

`BASKET_GRASP` 동작의 기준 소스입니다.

바구니에서 의류를 가져오는 동작에 필요한 기존 로봇 제어 구조와 보정 정보를 제공합니다.

현재 Full-Auto Runtime에서는 바구니 파지 동작이 Runtime 구조에 통합되어 있으며, 본 파일은 소스 의존성 및 무결성 검사 대상으로 함께 유지됩니다.

---

### 54-3.py

`OUTER_PULL` 동작 모듈입니다.

의류 영역과 하의 특징점을 이용하여 의류 외곽의 파지 위치를 계산합니다.

계산된 위치를 두 로봇팔이 파지한 뒤 바깥 방향으로 당겨 하의를 펼치는 동작을 계획하고 실행합니다.

---

### 55-5.py

`PRESS_SWEEP` 동작 모듈입니다.

주름 정보와 의류 형태를 이용하여 주름 또는 접힘 영역을 찾습니다.

검출된 영역을 로봇팔로 누른 상태에서 바깥 방향으로 쓸어 주름이나 접힘을 완화하는 동작을 계획하고 실행합니다.

---

### 58-3.py

`POSITION_ADJUST` 동작 모듈입니다.

하의의 현재 위치와 폴딩보드 작업영역을 분석하여 이후 조작을 수행하기 좋은 위치로 의류를 재배치합니다.

완전 자동 Runtime에서는 `BASKET_GRASP` 이후 `POSITION_ADJUST`를 먼저 수행한 뒤, 새로 촬영한 영상을 이용한 자동 상태 판단 단계로 진입합니다.

---

### 60-15.py

`WAIST_PULL_LAYDOWN` 동작 모듈입니다.

하의 Pose를 이용하여 허리 영역과 두 로봇팔의 파지 위치를 계산합니다.

두 로봇팔로 허리 부분을 파지하여 의류를 펼친 뒤 다시 폴딩보드 위에 내려놓는 동작을 계획하고 실행합니다.

---

### align-11.py

`ALIGN` 동작 모듈입니다.

하의 Pose와 의류 형태를 이용하여 바지 중심축과 기준선 사이의 위치 및 방향 오차를 계산합니다.

계산된 오차를 기준으로 의류를 이동하거나 회전시켜 폴딩보드의 목표 위치에 맞게 정렬합니다.

---

## 8. 하의 인식 모듈

현재 Full-Auto Runtime에서는 다음 세 개의 하의 인식 모듈을 사용합니다.

```text
step_e49_bottom_perception.py
step_e62_bottom_perception.py
step_d25_v2.py
```

이 파일들은 기존에 실제 로봇에서 검증한 동작 Runtime의 연결 구조를 유지하기 위해 함께 사용됩니다.

주요 연결 대상은 다음과 같습니다.

```text
54-3.py
55-5.py
60-15.py
align-11.py
```

각 동작 모듈은 Runtime 실행 중 하의 영역, Pose, 주름 및 형태 분석 결과를 이용하여 실제 파지점과 이동 경로를 계산합니다.

---

## 9. step_e49_bottom_perception.py

하의 영역 분할과 기본적인 형태 분석을 담당하는 인식 모듈입니다.

주요 기능은 다음과 같습니다.

* 의류 영역 분할
* 하의 Mask 선택
* 하의 관찰 정보 생성
* Pose 및 형태 분석을 위한 기본 정보 제공
* Mask 및 하의 구조 분석

대표 Runtime API는 다음과 같습니다.

```text
BottomObservation
infer_bottoms_mask()
parse_class_names()
```

본 모듈은 카메라 영상에서 하의 상태를 분석하는 역할을 담당하며, 로봇에 직접 이동 명령을 보내는 제어 Runtime은 아닙니다.

---

## 10. step_e62_bottom_perception.py

하의 Pose, 주름, 형태 및 허리 영역 분석을 확장한 인식 모듈입니다.

주요 기능은 다음과 같습니다.

* 빛 반사 영향 완화
* 주름 Heatmap 분석
* 하의 Pose 추론
* Pose 기반 의류 영역 재검출
* 허리 영역 상태 분석
* 동작 판단에 필요한 형태 정보 생성
* 작업 완료 여부 판단 보조

대표 Runtime API는 다음과 같습니다.

```text
suppress_specular_reflections()
build_wrinkle_heatmap()
infer_bottom_pose()
_e52_pose_guided_segmentation_retry()
evaluate_waist_lift_semantics()
```

---

## 11. step_d25_v2.py

기준 영상 없이 현재 하의의 형태와 작업 완료 가능성을 평가하는 인식 모듈입니다.

주요 분석 요소는 다음과 같습니다.

* 허리 구조
* 가랑이의 오목한 형태
* 양쪽 다리 구조
* 밑단 구조
* Pose 특징점
* 외곽선 형태
* 볼록도 변화
* 큰 접힘
* 추가 조작 필요 여부

미세한 주름이나 의류 자체에서 자연스럽게 발생하는 고유 주름보다 실제로 추가 조작이 필요한 큰 접힘과 구조적인 이상 상태를 중심으로 판단하도록 사용됩니다.

본 모듈 역시 로봇에 직접 이동 명령을 보내는 동작 Runtime이 아니라 의류 상태를 분석하는 역할을 담당합니다.

---

## 12. step_d23_v2 호환 구조

`step_d25_v2.py`는 Runtime 실행 과정에서 `step_d23_v2`라는 이름으로 참조될 수 있습니다.

하지만 현재 V38 Runtime에서는 별도의 `step_d23_v2.py` 파일을 사용하지 않습니다.

동작 모듈이 D25를 불러오기 전에 현재 모듈을 다음과 같이 `step_d23_v2` 이름으로 등록합니다.

```python
sys.modules.setdefault("step_d23_v2", sys.modules[__name__])
```

해당 호환 구조를 사용하는 주요 모듈은 다음과 같습니다.

```text
54-3.py
55-5.py
60-15.py
align-11.py
```

따라서 Import 이름만 보고 별도의 `step_d23_v2.py` 파일을 추가하지 않습니다.

---

## 13. AI 모델

### 의류 영역 분할 모델

```text
SW/Jetson/models/segmentation/
└── kfashion_yolo26s_seg3_e100_best.engine
```

TensorRT 기반 의류 영역 분할 모델입니다.

상의와 하의 Runtime에서 공통으로 사용합니다.

검증된 SHA-256:

```text
ec4b0bcfd6812a0723ad79d00fdc56faef3cd25d1476beee9de4fc9062071725
```

---

### 하의 Pose 모델

```text
SW/Jetson/models/pose/lower/
└── bottom_pose8_yolo26m_robot_beige_retrain_all_v2.engine
```

V38 완전 자동 하의 Runtime에서 사용하는 Bottom Pose TensorRT Engine입니다.

허리, 가랑이, 양쪽 밑단 등 하의 조작에 필요한 주요 특징점을 검출합니다.

검증된 SHA-256:

```text
d40861c7db06b59bda50016fe2041b8d566d18060ff5f1ab1199d06a1ee7646f
```

기존 하의 Runtime에서 사용하던 이전 Pose Engine 대신 현재 V38 Runtime에서는 위 모델을 사용합니다.

---

## 14. 카메라

사용 카메라:

```text
ELP OV2710
해상도: 1280 × 720
카메라 장치: /dev/video0
```

카메라 설정 파일:

```text
SW/Jetson/preprocessing/lower/dual/
└── elp_ov2710_camera_controls.json
```

현재 V38 Runtime의 카메라 설정에는 다음 값이 포함됩니다.

```text
auto_exposure = 1
exposure_time_absolute = 151
gain = 0
power_line_frequency = 2
white_balance_automatic = 0
white_balance_temperature = 4600
```

카메라 왜곡 보정 코드:

```text
SW/Jetson/preprocessing/lower/dual/undistort/
└── camera_undistort.py
```

현재 `run_lower.py`에서 사용하는 카메라 내부 보정값은 다음 공용 카메라 파일입니다.

```text
SW/Jetson/common/camera/
└── elp_ov2710_1280x720_calibration.npz
```

검증된 SHA-256:

```text
343cc5b96b2417603510938ae49ca29aed9265618b23fc6c57392d12439befa6
```

---

## 15. 하의 전용 Homography

완전 자동 하의 Runtime은 다음 하의 전용 Homography 파일을 사용합니다.

```text
SW/Jetson/preprocessing/lower/dual/undistort/
└── elp_ov2710_folding_board_homography_cache.json
```

해당 파일은 다음 정보를 포함합니다.

```text
H
raw_H
camera_geometry
schema_version
```

하의 Runtime은 원본 영상과 왜곡 보정 영상의 좌표계를 구분하여 사용하므로 `raw_H`와 `camera_geometry`가 포함된 하의 전용 Homography가 필요합니다.

검증된 SHA-256:

```text
0a59a7a25f09af2edd235f5ee881ec48c9c52736200f7e91ed69ab1726b26a45
```

공용 보정 디렉터리에도 비슷한 이름의 폴딩보드 Homography가 존재하지만 두 파일은 내용과 Runtime 용도가 다릅니다.

따라서 다음과 같은 변경을 수행하면 안 됩니다.

```text
하의 전용 Homography를 공용 Homography 위에 덮어쓰기
공용 Homography를 하의 전용 Homography 위에 덮어쓰기
두 Homography 파일을 하나로 통합
JSON Key 구조를 임의 변경
```

---

## 16. 공용 로봇 / 폴딩보드 보정 파일

현재 하의 Runtime에서 사용하는 공용 보정 파일은 다음과 같습니다.

```text
SW/Jetson/common/calibration/
├── dual_roarm_folding_board_config.json
└── basket_arm2_5point_affine.json
```

로봇 / 폴딩보드 설정 파일 SHA-256:

```text
dual_roarm_folding_board_config.json
807cc17db34cf48ba1e0eb7c770670a27e3370beee4c3d237659bfb6455c2373
```

바구니 보정 파일 SHA-256:

```text
basket_arm2_5point_affine.json
546dc9c74cc629e407bad4967b9c94d267012e85bd0ef0d86ac5fe73a536d8d8
```

---

## 17. V38 주요 실행 키

현재 V38 완전 자동 Runtime의 주요 키는 다음과 같습니다.

| 키 | 기능 |
| --- | --- |
| `E` | 빈 폴딩보드 기준 영상 획득 |
| `L` | Homography 고정 |
| `X` | 완전 자동 작업 시작 |
| `Q` / `ESC` | 프로그램 종료 / 긴급 중단 |

기존 사용자 개입 Runtime에서 사용했던 숫자 동작 선택 키와 `ENTER` 기반 동작 승인 과정은 현재 V38 Runtime의 기본 운용 방식이 아닙니다.

V38에서는 `X` 입력 이후 완전 자동 작업이 시작되며, 시스템이 새로 획득한 영상을 바탕으로 다음 동작을 자동으로 결정합니다.

---

## 18. 의존성 검사

저장소 최상위 디렉터리에서 다음 명령을 사용합니다.

```bash
cd /workspace/2026ESWContest_free_Otgaestra
```

실제 로봇 또는 카메라 Runtime을 시작하지 않고 GitHub 제출본의 필수 파일 존재 여부 및 SHA-256을 검사합니다.

```bash
python3 SW/Jetson/preprocessing/lower/run_lower.py --paths-only
```

현재 V38 GitHub 제출본에서 확인된 결과는 다음과 같습니다.

```text
PASS=20
FAIL=0
TOTAL=20
```

검사 대상에는 다음 항목이 포함됩니다.

```text
V38 완전 자동 Runtime
V23 Full-Auto Runtime 기반 코드
Main33 Runtime
50-1.py
54-3.py
55-5.py
58-3.py
60-15.py
align-11.py
E49 하의 인식 모듈
E62 하의 인식 모듈
D25 하의 인식 모듈
카메라 왜곡 보정 코드
카메라 보정값
하의 전용 Homography
카메라 설정
로봇 / 폴딩보드 설정
바구니 보정값
Segmentation TensorRT Engine
Bottom Pose TensorRT Engine
```

---

## 19. Python 소스 검증

현재 완전 자동 Runtime 전체에 대해 Python `py_compile` 검사를 수행했습니다.

검증 대상은 다음과 같습니다.

```text
bottom_vla-38_submission_full_auto.py
bottom_vla-23_submission_runtime.py
main-33_submission_runtime.py
50-1.py
54-3.py
55-5.py
58-3.py
60-15.py
align-11.py
step_e49_bottom_perception.py
step_e62_bottom_perception.py
step_d25_v2.py
camera_undistort.py
run_lower.py
```

검증 결과:

```text
PASS=14
FAIL=0
TOTAL=14
```

E49 / E62 인식 모듈의 일반 Python Import도 별도로 검증했습니다.

실제 Import 결과는 다음 `dual/undistort/` 소스로 연결되었습니다.

```text
SW/Jetson/preprocessing/lower/dual/undistort/
├── step_e49_bottom_perception.py
└── step_e62_bottom_perception.py
```

필수 Runtime API 검사 결과:

```text
NORMAL IMPORT/API SUMMARY: FAIL=0
```

---

## 20. 실행 방법

저장소 최상위 디렉터리:

```bash
cd /workspace/2026ESWContest_free_Otgaestra
```

### 의존성 검사

```bash
python3 SW/Jetson/preprocessing/lower/run_lower.py --paths-only
```

이 방식에서는 실제 Runtime을 시작하지 않습니다.

---

### 모의 실행

```bash
python3 SW/Jetson/preprocessing/lower/run_lower.py --dry-run
```
실제 로봇 동작 없이 Runtime 초기화, TensorRT 모델 로딩 및 주요 실행 구성을 확인합니다.
`run_lower.py`의 기본 실행 방식도 `dry-run`입니다.

---

### 실제 로봇 Runtime

```bash
python3 SW/Jetson/preprocessing/lower/run_lower.py --physical
```

`--physical` 옵션을 사용하면 실제 두 대의 RoArm M2-S를 이용한 의류 조작 Runtime이 활성화됩니다.

---

## 21. 실제 로봇 Runtime 실행 시 주의사항

`--physical` 옵션을 실행하기 전 반드시 다음 항목을 확인해야 합니다.

```text
ARM1 전원 및 연결 상태
ARM2 전원 및 연결 상태
/dev/roarm_1
/dev/roarm_2
카메라 /dev/video0
폴딩보드 작업영역 상태
로봇 이동 경로 내 장애물 여부
사람이 로봇 작업영역 내부에 없는지 여부
비상 전원 차단 가능 여부
카메라 보정 상태
Homography 상태
바구니 보정 상태
```

로봇 포트:

```text
ARM1: /dev/roarm_1
ARM2: /dev/roarm_2
```

또한 `--hover` 방식은 완전히 로봇 명령이 발생하지 않는 Runtime으로 간주하지 않습니다.

하위 Runtime 구조에 따라 `hover` 방식에서도 로봇 명령과 연결될 가능성이 있으므로, 전원이 켜진 로봇 환경에서 단순한 의존성 검증을 위해 사용하지 않습니다.

정적 파일 검증에는 반드시 다음 방식을 권장합니다.

```bash
--paths-only
```

---

## 22. 생성 파일

Runtime 실행 과정에서 사용하는 임시 결과 및 디버그 출력은 가능한 경우 다음 디렉터리에서 관리합니다.

```text
SW/Jetson/preprocessing/lower/outputs/
```

예:

```text
빈 폴딩보드 기준 영상
Runtime 실행 중 생성되는 영상
중간 분석 결과
디버그 출력
```

GitHub 제출본에서는 Runtime 실행 과정에서 생성되는 임시 이미지 및 Python 캐시를 제외합니다.

```text
outputs/
__pycache__/
*.py[cod]
```

---

## 23. Runtime 소스 무결성 주의사항

하의 Runtime은 여러 소스 파일을 실행 중 동적으로 연결합니다.

따라서 다음 사항을 유지해야 합니다.

* 검증된 Python Runtime 파일명을 임의로 변경하지 않습니다.
* Runtime 소스 디렉터리 구조를 임의로 변경하지 않습니다.
* 전체 소스 파일을 자동 정리 도구로 일괄 수정하지 않습니다.
* 동적 소스 연결 구조를 임의로 일반적인 Import 구조로 변경하지 않습니다.
* 하의 전용 Homography와 공용 Homography를 통합하지 않습니다.
* 별도의 `step_d23_v2.py` 파일을 임의로 추가하지 않습니다.
* E49 / E62 / D25 인식 모듈을 지정된 위치에 유지합니다.
* TensorRT Engine 파일을 다른 Pose 모델과 임의 교체하지 않습니다.
* 검증 없이 동작 Runtime 소스 파일의 이름을 변경하지 않습니다.

Main Runtime은 일부 소스 파일에 대해 Runtime 실행 중 소스 무결성을 검사합니다.

소스가 검증된 상태와 다르다고 판단되면 안전을 위해 로봇 동작을 차단할 수 있습니다.

GitHub 제출본에서는 단순히 코드 중복을 줄이는 것보다 **실제 로봇 Runtime의 재현성과 검증된 의존성 구조를 유지하는 것을 우선합니다.**

---

## 24. 검증 환경

현재 V38 Runtime의 개발 및 검증 환경은 다음과 같습니다.

```text
NVIDIA Jetson Orin Nano
Ubuntu 22.04.3
Python 3.10.12
TensorRT 10.7.0
OpenCV 4.11.0
PyTorch 2.10.0
PyTorch CUDA 12.6
NumPy 1.26.4
Ultralytics 8.4.45
XGBoost 3.2.0
Docker 29.7.2
```

---

## 25. 현재 V38 제출본 검증 상태

현재 V38 GitHub 제출본에서 완료한 검증은 다음과 같습니다.

```text
V38 의존성 SHA / 경로 검사
PASS=20 FAIL=0

하의 전용 Homography 구조 검사
PASS

Python py_compile
PASS=14 FAIL=0

E49 일반 Import
PASS

E62 일반 Import
PASS

필수 Runtime API 검사
FAIL=0
```

이전 사용자 개입 방식의 하의 Runtime에서 수행했던 새 저장소 복제 및 초기 실행 환경 검증 결과는 현재 V38 완전 자동 Runtime의 검증 결과로 간주하지 않습니다.

V38 Repository 기준 재현성 검증은 최종 GitHub 제출본을 기준으로 별도로 수행합니다.

---

## 26. 이전 Runtime과의 차이

이전 하의 Runtime은 사용자가 현재 하의 상태를 보고 다음 동작을 직접 선택하는 사용자 개입 방식이었습니다.

기존 방식:

```text
의류 상태 인식
    ↓
사용자가 다음 동작 선택
    ↓
동작 계획 생성
    ↓
사용자 실행 승인
    ↓
로봇 동작 실행
```

현재 V38 완전 자동 Runtime에서는 다음 동작을 선택하는 과정까지 자동화했습니다.

현재 방식:

```text
의류 상태 인식
    ↓
현재 상태 판단
    ↓
다음 동작 자동 결정
    ↓
동작 계획 생성
    ↓
로봇 동작 실행
    ↓
새 영상 재관찰
    ↓
다음 동작 자동 결정
```

따라서 사용자가 각 조작 단계마다 다음 동작을 직접 선택하지 않아도 Runtime이 현재 의류 상태를 분석하여 필요한 동작을 스스로 결정할 수 있습니다.

---

## 27. 최종 구현 범위 및 요약

현재 V38 하의 Runtime은 다음과 같은 폐루프(Closed-loop) 구조를 구현합니다.

```text
카메라 영상 획득
    ↓
의류 상태 인식
    ↓
현재 하의 상태 판단
    ↓
다음 동작 자동 결정
    ↓
동작 계획 생성
    ↓
두 로봇팔을 이용한 조작
    ↓
새 영상 재관찰
    ↓
상태 재평가
    ↓
다음 동작 결정
    ↓
FINISH
```

각 동작의 세부 조작 계획은 기존에 실제 로봇에서 검증한 동작 Runtime을 그대로 활용하면서, 상위 단계에서 현재 의류 상태를 분석하고 다음 동작을 자동으로 선택하도록 구성했습니다.

현재 하의 완전 자동 Runtime은 다음 기술을 결합합니다.

* TensorRT 기반 의류 영역 분할
* Bottom Pose 추론
* Mask 및 외곽선 형태 분석
* 주름 및 접힘 분석
* 기준 영상 없이 수행하는 작업 완료 여부 판단
* 카메라 왜곡 보정
* Homography 기반 좌표 변환
* 폴딩보드 보정
* 바구니 위치 보정
* 두 대의 RoArm M2-S 제어
* 고정 동작 계획(Frozen Plan)
* 다음 동작 자동 결정
* 동작 후 새 영상 재관찰
* 반복적인 상태 재평가
* 자동 `FINISH` 판단

최종 Runtime 실행 흐름은 다음과 같습니다.

```text
의류 상태 인식
    ↓
현재 상태 판단
    ↓
다음 동작 자동 결정
    ↓
동작 계획 생성
    ↓
로봇 동작 실행
    ↓
새 영상 재관찰
    ↓
다음 동작 자동 결정
    ↓
FINISH
```

즉 현재 V38 Runtime은 기존의 수동 동작 선택 방식에서 확장되어, **하의 상태 인식부터 다음 조작 선택, 두 로봇팔을 이용한 실제 의류 조작, 재관찰 및 종료 조건 판단까지 반복적으로 수행하는 완전 자동 하의 정리 Runtime**으로 구성되어 있습니다.

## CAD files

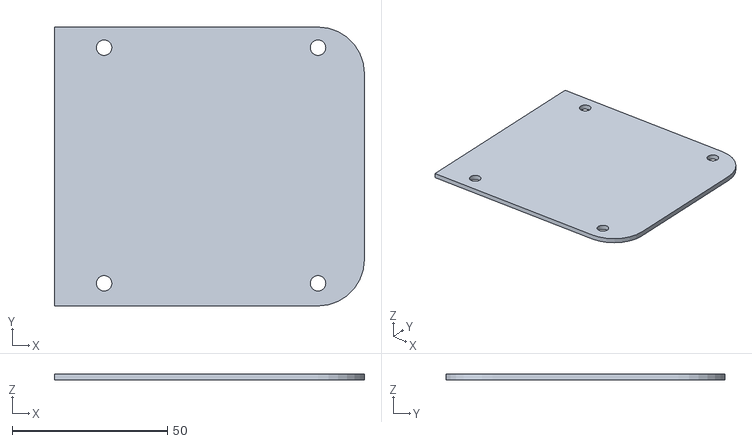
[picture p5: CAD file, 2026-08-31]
HW/roarm_plate.stl
100.0 x 90.0 x 2.00

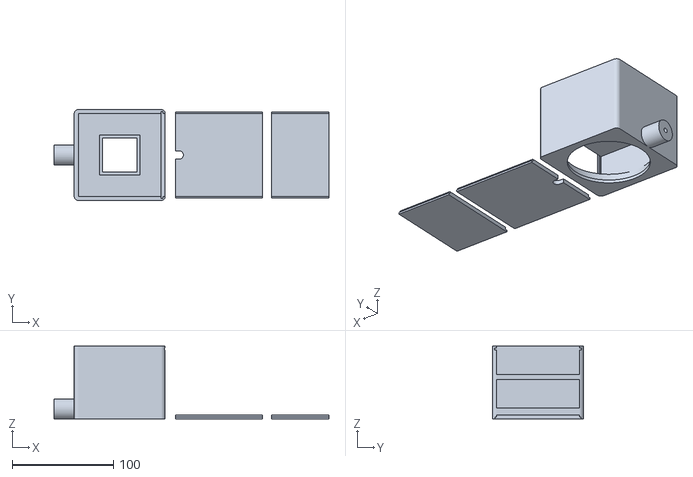
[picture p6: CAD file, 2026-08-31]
HW/elp_cam_holder.stl
272.0 x 90.0 x 72.2

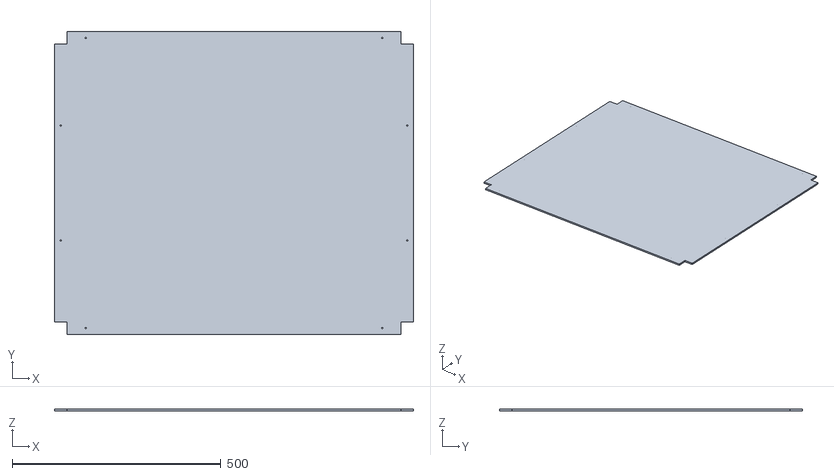
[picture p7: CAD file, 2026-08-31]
HW/bottom_floor.stl
860.0 x 725.0 x 5.00

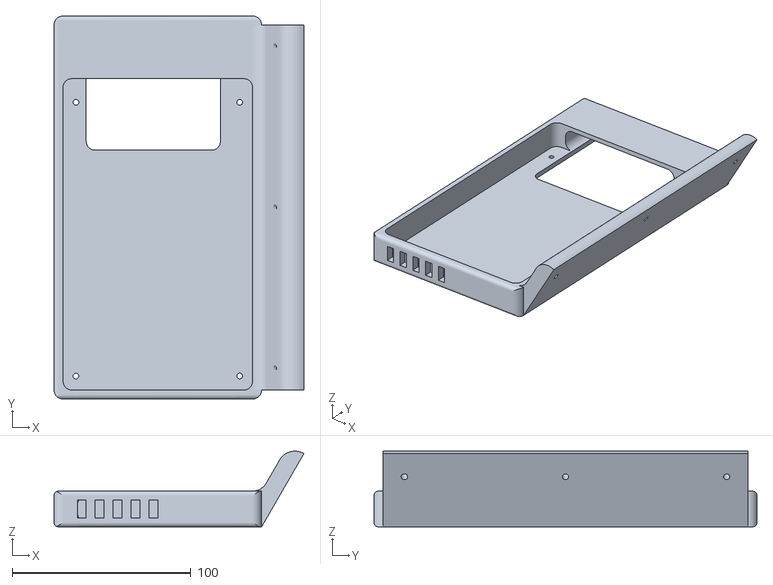
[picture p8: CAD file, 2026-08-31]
HW/display_case.stl
139.7 x 214.0 x 42.3

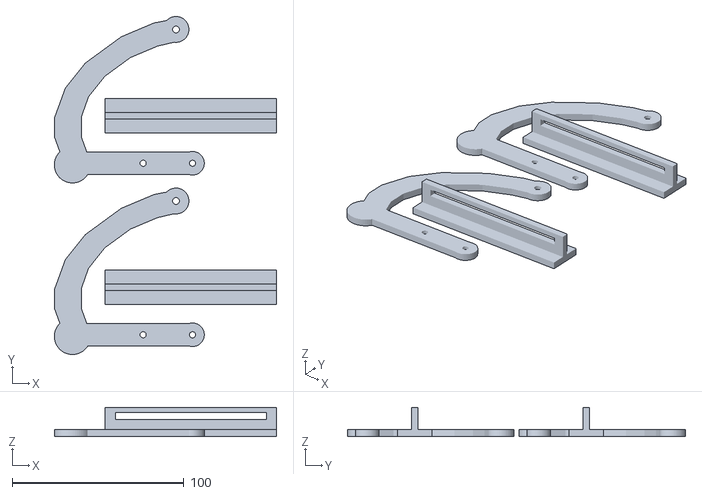
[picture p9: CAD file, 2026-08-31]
HW/door_bracket_fall.stl
129.6 x 197.0 x 17.0

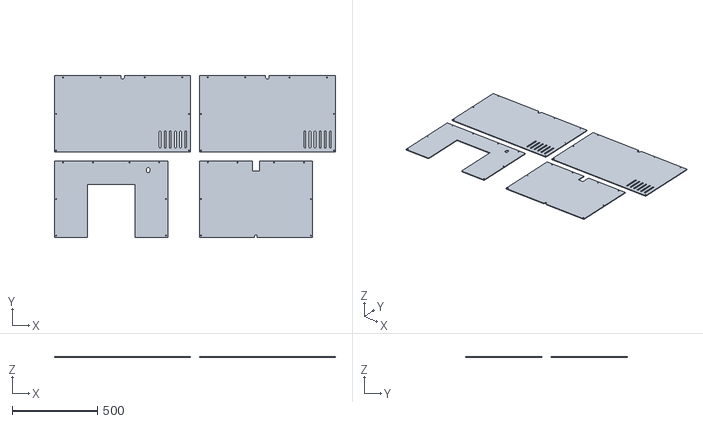
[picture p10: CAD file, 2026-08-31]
HW/beside_plate.stl
1650.0 x 950.0 x 5.00

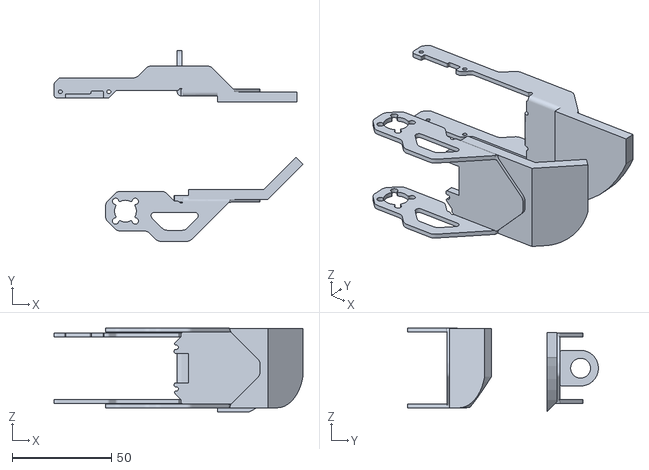
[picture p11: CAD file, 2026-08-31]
HW/gripper.stl
125.4 x 96.1 x 42.2

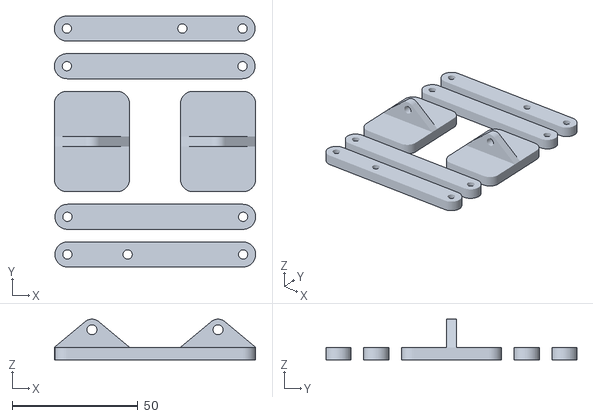
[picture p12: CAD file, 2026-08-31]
HW/door_bracket_fold.stl
80.2 x 100.0 x 16.2

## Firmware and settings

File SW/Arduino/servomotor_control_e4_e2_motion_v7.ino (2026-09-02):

#include <Servo.h>

/*
  Jerber folding-board controller e4/e2 motion V7

  Design rule:
    - e2 behavior is preserved as the baseline.
    - Startup still calls attachAndHomeAll(), so servo torque holds from boot.
    - 1..5, S, F, X, D, H and ? retain the e2 behavior.
    - Only G/g is added for the synchronized showcase sequence used by the display UI.

  Display UI compatibility:
    PROTO:JERBER_E4_E2_MOTION_V7
    G -> synchronized one-shot sequence -> DONE

  V7 motion baseline:
    - Servo start/operate angles are copied exactly from servomotor_control_e2.ino.
    - Manual plate commands 1..5 preserve the original e2 toggle behavior.
    - Servos attach and hold torque from boot, as in e2 (D releases torque).
    - Manual operate hold: 1000 ms.
    - Manual return hold: 1000 ms.
    - Manual return profile: 2 deg / 10 ms.
    - The synchronized G scenario/order and stage waits are preserved.
*/

const int SERVO_COUNT = 8;
const int PLATE_COUNT = 5;

const int servoPins[SERVO_COUNT] = {
  2, 3, 4, 5, 6, 7, 8, 9
};

Servo servos[SERVO_COUNT];

// Unique build identity. The UI checks this as well as PROTO so an older V6/V7
// binary can no longer be mistaken for the sketch you just uploaded.
const char BUILD_ID[] = "JERBER_E4_E2_MOTION_V7_B1_20260817";

// Exact plate-5 targets copied from the user-supplied servomotor_control_e2.ino.
const int E2_P5_PIN8_START = 158;
const int E2_P5_PIN8_OPERATE = 98;
const int E2_P5_PIN9_START = 14;
const int E2_P5_PIN9_OPERATE = 74;

/*
  배열 순서:
  인덱스    0  1  2  3  4  5  6  7
  핀 번호   2  3  4  5  6  7  8  9
*/

int startAngles[SERVO_COUNT] = {
  160, 20, 24, 156, 160, 154, E2_P5_PIN8_START, E2_P5_PIN9_START
};

int operateAngles[SERVO_COUNT] = {
  60, 120, 120, 60, 25, 25, E2_P5_PIN8_OPERATE, E2_P5_PIN9_OPERATE
};

// 현재 각 서보에 마지막으로 명령한 각도
int currentAngles[SERVO_COUNT];

/*
  플레이트와 서보 인덱스 연결

  1번 플레이트: 핀 4, 5 → 서보 인덱스 2, 3
  2번 플레이트: 핀 2, 3 → 서보 인덱스 0, 1
  3번 플레이트: 핀 6    → 서보 인덱스 4
  4번 플레이트: 핀 7    → 서보 인덱스 5
  5번 플레이트: 핀 8, 9 → 서보 인덱스 6, 7

  두 번째 값이 -1이면 단일 서보 플레이트
*/
const int plateServoA[PLATE_COUNT] = {
  2, 0, 4, 5, 6
};

const int plateServoB[PLATE_COUNT] = {
  3, 1, -1, -1, 7
};

// false: 초기 위치, true: 동작 위치
bool plateOperated[PLATE_COUNT] = {
  false, false, false, false, false
};

// 동작 위치에 도착한 후 대기
const unsigned long OPERATE_WAIT_MS = 1000;

// 천천히 복귀한 후 대기
const unsigned long RETURN_WAIT_MS = 1000;

// 다음 플레이트 동작 전 대기
const unsigned long NEXT_WAIT_MS = 500;

// detach 후 다시 연결했을 때 초기 위치 복귀 대기
const unsigned long REATTACH_WAIT_MS = 2000;

/*
  복귀 속도 설정

  2도 이동하고 10ms 대기:
  약 200도/초의 명령 속도

  더 느리게:
  RETURN_STEP_DEGREES = 1
  또는
  RETURN_STEP_DELAY_MS = 20

  더 빠르게:
  RETURN_STEP_DEGREES = 3
*/
const int RETURN_STEP_DEGREES = 2;
const unsigned long RETURN_STEP_DELAY_MS = 10;

// ------------------------------------------------------------
// e4 addition: synchronized G scenario only
// ------------------------------------------------------------
// First 1+2 full-rise hold requested by the user.
const unsigned long SYNC_INITIAL_WAIT_MS = 1000;
// Interlock between plates 1+2 and plate 3/4 motion.
const unsigned long SYNC_INTERLOCK_WAIT_MS = 500;
// Existing showcase settle waits after an auxiliary plate reaches its target.
const unsigned long SYNC_STAGE_WAIT_MS = 650;
const unsigned long SYNC_FINAL_WAIT_MS = 900;

// Smooth multi-plate interpolation used only by G.
const int SYNC_STEP_DEGREES = 2;
const unsigned long SYNC_STEP_DELAY_MS = 10;

enum ControllerState {
  STOPPED_HOLD,
  STARTING_REPEAT,
  RUNNING_REPEAT,
  STARTING_ONE_SHOT,
  RUNNING_ONE_SHOT,
  // e4 addition: G has its own state so F/S keep the original e2 flow.
  STARTING_SYNC_G,
  RUNNING_SYNC_G,
  MANUAL_MOVING,
  DETACHED
};

ControllerState controllerState = STOPPED_HOLD;
unsigned long startingSince = 0;

// Explicit prototypes (Arduino IDE would auto-generate these; keeping them here
// also makes static C++ syntax checking straightforward).
void handleSerialCommands();
void togglePlate(int plateIndex);
void commandPlateOperate(int plateIndex);
bool slowReturnPlate(int plateIndex, ControllerState requiredState);
bool movePlateCycle(int plateIndex, ControllerState requiredState);
void startSequence();
void startOneShotFold();
void startSynchronizedG();
void stopAndHold();
void homeAndHold();
void stopAndDetach();
void attachAndHomeAll();
void resetPlateStates();
bool anyPlateOperated();
void printStatus();
bool waitWhileState(unsigned long waitTime, ControllerState requiredState);
int syncRatioAngle(int servoIndex, float ratio);
void syncSetPlateTarget(int targets[SERVO_COUNT], int plateIndex, float ratio);
bool syncMoveToTargets(const int targets[SERVO_COUNT], ControllerState requiredState);
bool syncMoveRatios(float p1, float p2, float p3, float p4, float p5, ControllerState requiredState);
bool runSynchronizedGSequence(ControllerState requiredState);

void setup() {
  Serial.begin(9600);

  attachAndHomeAll();
  delay(2000);

  Serial.println(F(""));
  Serial.println(F("================================"));
  Serial.println(F("Jerber e4/e2 motion V7 controller ready."));
  Serial.println(F("================================"));
  Serial.println(F("1: Plate 1 toggle - pins 4, 5"));
  Serial.println(F("2: Plate 2 toggle - pins 2, 3"));
  Serial.println(F("3: Plate 3 toggle - pin 6"));
  Serial.println(F("4: Plate 4 toggle - pin 7"));
  Serial.println(F("5: Plate 5 toggle - pins 8, 9"));
  Serial.println(F(""));
  Serial.println(F("S: start repeating automatic sequence"));
  Serial.println(F("F: run one folding sequence, then send DONE"));
  Serial.println(F("G: run synchronized display-UI sequence, then send DONE"));
  Serial.println(F("X: stop and return home"));
  Serial.println(F("D: stop and detach"));
  Serial.println(F("H: return home and hold"));
  Serial.println(F("?: status"));
  Serial.println(F("================================"));
  Serial.println(F("PROTO:JERBER_E4_E2_MOTION_V7"));
  Serial.print(F("BUILD:"));
  Serial.println(BUILD_ID);
  Serial.println(F("E2_P5:PIN8=158->98 PIN9=14->74"));
  Serial.println(F("READY"));
}

void loop() {
  handleSerialCommands();

  // e4 addition: G uses its own one-shot state machine.
  // Existing e2 S/F flow below remains unchanged.
  if (controllerState == STARTING_SYNC_G) {
    if (millis() - startingSince >= REATTACH_WAIT_MS) {
      controllerState = RUNNING_SYNC_G;
      Serial.println(F("FOLDING"));
      Serial.println(F("[G] START synchronized one-shot sequence."));
    }
    delay(5);
    return;
  }

  if (controllerState == RUNNING_SYNC_G) {
    if (!runSynchronizedGSequence(RUNNING_SYNC_G)) {
      return;
    }

    if (controllerState == RUNNING_SYNC_G) {
      controllerState = STOPPED_HOLD;
      resetPlateStates();
      Serial.println(F("[G] DONE synchronized one-shot sequence."));
      Serial.println(F("DONE"));
    }
    return;
  }

  // Detached/manual states may require a home pass before a requested mode starts.
  if (controllerState == STARTING_REPEAT || controllerState == STARTING_ONE_SHOT) {
    if (millis() - startingSince >= REATTACH_WAIT_MS) {
      if (controllerState == STARTING_ONE_SHOT) {
        controllerState = RUNNING_ONE_SHOT;
        Serial.println(F("FOLDING"));
        Serial.println(F("[FOLD] START one-shot sequence."));
      } else {
        controllerState = RUNNING_REPEAT;
        Serial.println(F("[START] Repeating automatic sequence started."));
      }
    }
    delay(5);
    return;
  }

  if (controllerState != RUNNING_REPEAT && controllerState != RUNNING_ONE_SHOT) {
    delay(5);
    return;
  }

  ControllerState requiredState = controllerState;
  for (int plateIndex = 0; plateIndex < PLATE_COUNT; plateIndex++) {
    if (!movePlateCycle(plateIndex, requiredState)) {
      return;
    }
  }

  if (requiredState == RUNNING_ONE_SHOT && controllerState == RUNNING_ONE_SHOT) {
    controllerState = STOPPED_HOLD;
    Serial.println(F("[FOLD] DONE one-shot sequence."));
    Serial.println(F("DONE"));
    return;
  }

  if (controllerState == RUNNING_REPEAT) {
    Serial.println(F("[AUTO] All plate operations complete."));
    waitWhileState(3000, RUNNING_REPEAT);
  }
}

void handleSerialCommands() {
  while (Serial.available() > 0) {
    char command = Serial.read();

    // 엔터, 줄바꿈, 공백 무시
    if (
      command == '\r' ||
      command == '\n' ||
      command == ' '
    ) {
      continue;
    }

    switch (command) {
      case '1':
        togglePlate(0);
        break;

      case '2':
        togglePlate(1);
        break;

      case '3':
        togglePlate(2);
        break;

      case '4':
        togglePlate(3);
        break;

      case '5':
        togglePlate(4);
        break;

      case 'S':
      case 's':
        startSequence();
        break;

      case 'F':
      case 'f':
        startOneShotFold();
        break;

      case 'G':
      case 'g':
        startSynchronizedG();
        break;

      case 'X':
      case 'x':
        stopAndHold();
        break;

      case 'D':
      case 'd':
        stopAndDetach();
        break;

      case 'H':
      case 'h':
        homeAndHold();
        break;

      case '?':
        printStatus();
        break;

      default:
        Serial.print(F("[ERROR] Unknown command: "));
        Serial.println(command);
        break;
    }
  }
}

/*
  숫자 1~5 수동 토글

  초기 위치 상태:
  startAngles → operateAngles

  동작 위치 상태:
  operateAngles → startAngles
  복귀할 때는 천천히 이동
*/
void togglePlate(int plateIndex) {
  if (plateIndex < 0 || plateIndex >= PLATE_COUNT) {
    return;
  }

  if (controllerState == RUNNING_REPEAT || controllerState == RUNNING_ONE_SHOT ||
      controllerState == RUNNING_SYNC_G) {
    Serial.println(
      F("[INFO] Stop automatic sequence before manual control.")
    );
    return;
  }

  if (controllerState == STARTING_REPEAT || controllerState == STARTING_ONE_SHOT ||
      controllerState == STARTING_SYNC_G) {
    Serial.println(
      F("[INFO] Servos are currently returning home.")
    );
    return;
  }

  if (controllerState == MANUAL_MOVING) {
    Serial.println(
      F("[INFO] Another plate is currently moving.")
    );
    return;
  }

  // D 명령으로 detach된 경우 다시 attach하고 초기 위치로 복귀
  if (controllerState == DETACHED) {
    controllerState = MANUAL_MOVING;

    attachAndHomeAll();

    Serial.println(F("[MANUAL] Servos attached."));
    Serial.println(F("[MANUAL] Returning home first."));

    if (!waitWhileState(REATTACH_WAIT_MS, MANUAL_MOVING)) {
      return;
    }
  } else {
    controllerState = MANUAL_MOVING;
  }

  Serial.print(F("[PLATE "));
  Serial.print(plateIndex + 1);
  Serial.print(F("] "));

  // 초기 위치라면 동작 위치로 이동
  if (!plateOperated[plateIndex]) {
    Serial.println(F("Moving to operate position."));

    commandPlateOperate(plateIndex);

    if (!waitWhileState(OPERATE_WAIT_MS, MANUAL_MOVING)) {
      return;
    }

    plateOperated[plateIndex] = true;

    Serial.print(F("[PLATE "));
    Serial.print(plateIndex + 1);
    Serial.println(F("] Operated position reached."));
  }

  // 동작 위치라면 초기 위치로 천천히 복귀
  else {
    Serial.println(F("Returning home slowly."));

    if (!slowReturnPlate(plateIndex, MANUAL_MOVING)) {
      return;
    }

    plateOperated[plateIndex] = false;

    if (!waitWhileState(RETURN_WAIT_MS, MANUAL_MOVING)) {
      return;
    }

    Serial.print(F("[PLATE "));
    Serial.print(plateIndex + 1);
    Serial.println(F("] Home position reached."));
  }

  if (controllerState == MANUAL_MOVING) {
    controllerState = STOPPED_HOLD;
  }
}

/*
  해당 플레이트를 동작 각도로 즉시 명령
*/
void commandPlateOperate(int plateIndex) {
  int servoA = plateServoA[plateIndex];
  int servoB = plateServoB[plateIndex];

  // Keep the e2 write() path exactly. For plate 5 we additionally guard the
  // constants so a later array edit cannot silently change pins 8/9.
  if (plateIndex == 4) {
    servos[6].write(E2_P5_PIN8_OPERATE);   // e2: pin 8 -> 98 deg
    currentAngles[6] = E2_P5_PIN8_OPERATE;
    servos[7].write(E2_P5_PIN9_OPERATE);   // e2: pin 9 -> 74 deg
    currentAngles[7] = E2_P5_PIN9_OPERATE;

    Serial.print(F("[P5-E2] BUILD="));
    Serial.print(BUILD_ID);
    Serial.print(F(" PIN8_TARGET="));
    Serial.print(E2_P5_PIN8_OPERATE);
    Serial.print(F(" PIN8_READ="));
    Serial.print(servos[6].read());
    Serial.print(F(" PIN8_US="));
    Serial.print(servos[6].readMicroseconds());
    Serial.print(F(" PIN9_TARGET="));
    Serial.print(E2_P5_PIN9_OPERATE);
    Serial.print(F(" PIN9_READ="));
    Serial.print(servos[7].read());
    Serial.print(F(" PIN9_US="));
    Serial.println(servos[7].readMicroseconds());
    return;
  }

  servos[servoA].write(operateAngles[servoA]);
  currentAngles[servoA] = operateAngles[servoA];

  if (servoB >= 0) {
    servos[servoB].write(operateAngles[servoB]);
    currentAngles[servoB] = operateAngles[servoB];
  }
}

/*
  플레이트를 초기 위치로 천천히 복귀

  한 쌍의 서보모터는 같은 시간 동안 움직이도록
  진행 비율을 계산하여 동시에 복귀시킨다.
*/
bool slowReturnPlate(
  int plateIndex,
  ControllerState requiredState
) {
  int servoA = plateServoA[plateIndex];
  int servoB = plateServoB[plateIndex];

  int fromA = currentAngles[servoA];
  int toA = startAngles[servoA];
  int deltaA = toA - fromA;

  int fromB = 0;
  int toB = 0;
  int deltaB = 0;

  if (servoB >= 0) {
    fromB = currentAngles[servoB];
    toB = startAngles[servoB];
    deltaB = toB - fromB;
  }

  int maxDistance = abs(deltaA);

  if (servoB >= 0) {
    maxDistance = max(maxDistance, abs(deltaB));
  }

  if (maxDistance == 0) {
    return true;
  }

  int totalSteps =
    (maxDistance + RETURN_STEP_DEGREES - 1) /
    RETURN_STEP_DEGREES;

  for (int step = 1; step <= totalSteps; step++) {
    int nextAngleA =
      fromA + ((long)deltaA * step) / totalSteps;

    servos[servoA].write(nextAngleA);
    currentAngles[servoA] = nextAngleA;

    if (servoB >= 0) {
      int nextAngleB =
        fromB + ((long)deltaB * step) / totalSteps;

      servos[servoB].write(nextAngleB);
      currentAngles[servoB] = nextAngleB;
    }

    if (
      !waitWhileState(
        RETURN_STEP_DELAY_MS,
        requiredState
      )
    ) {
      return false;
    }
  }

  // 계산 오차 방지를 위해 마지막에 정확한 초기 각도 명령
  servos[servoA].write(toA);
  currentAngles[servoA] = toA;

  if (servoB >= 0) {
    servos[servoB].write(toB);
    currentAngles[servoB] = toB;
  }

  return true;
}

/*
  S 명령 자동 시퀀스에서 사용

  동작 위치까지 빠르게 이동한 후
  초기 위치로 천천히 복귀
*/
bool movePlateCycle(int plateIndex, ControllerState requiredState) {
  if (controllerState != requiredState) {
    return false;
  }

  Serial.print(F("[AUTO] Plate "));
  Serial.print(plateIndex + 1);
  Serial.println(F(" operating."));

  commandPlateOperate(plateIndex);

  if (!waitWhileState(OPERATE_WAIT_MS, requiredState)) {
    return false;
  }

  plateOperated[plateIndex] = true;

  Serial.print(F("[AUTO] Plate "));
  Serial.print(plateIndex + 1);
  Serial.println(F(" returning slowly."));

  if (!slowReturnPlate(plateIndex, requiredState)) {
    return false;
  }

  plateOperated[plateIndex] = false;

  if (!waitWhileState(RETURN_WAIT_MS, requiredState)) {
    return false;
  }

  return waitWhileState(NEXT_WAIT_MS, requiredState);
}

void startSequence() {
  if (controllerState == RUNNING_REPEAT) {
    Serial.println(F("[INFO] Repeating automatic sequence is already running."));
    return;
  }
  if (controllerState == RUNNING_ONE_SHOT) {
    Serial.println(F("[INFO] One-shot fold is running. Use X/D/H to interrupt."));
    return;
  }
  if (controllerState == RUNNING_SYNC_G || controllerState == STARTING_SYNC_G) {
    Serial.println(F("[INFO] Synchronized G sequence is running. Use X/D/H to interrupt."));
    return;
  }
  if (controllerState == STARTING_REPEAT || controllerState == STARTING_ONE_SHOT) {
    Serial.println(F("[INFO] Servos are returning home."));
    return;
  }
  if (controllerState == MANUAL_MOVING) {
    Serial.println(F("[INFO] A plate is currently moving."));
    return;
  }

  if (controllerState == DETACHED || anyPlateOperated()) {
    attachAndHomeAll();
    controllerState = STARTING_REPEAT;
    startingSince = millis();
    Serial.println(F("[STARTING] Returning all plates home for repeating mode."));
    return;
  }

  controllerState = RUNNING_REPEAT;
  Serial.println(F("[START] Repeating automatic sequence started."));
}

void startOneShotFold() {
  if (controllerState == RUNNING_SYNC_G || controllerState == STARTING_SYNC_G) {
    Serial.println(F("[INFO] Synchronized G sequence is running. Use X/D/H to interrupt."));
    return;
  }
  if (controllerState == RUNNING_ONE_SHOT || controllerState == STARTING_ONE_SHOT) {
    Serial.println(F("[INFO] One-shot fold is already running."));
    return;
  }
  if (controllerState == RUNNING_REPEAT || controllerState == STARTING_REPEAT) {
    Serial.println(F("[INFO] Stop repeating mode with X before one-shot F."));
    return;
  }
  if (controllerState == MANUAL_MOVING) {
    Serial.println(F("[INFO] A plate is currently moving."));
    return;
  }

  if (controllerState == DETACHED || anyPlateOperated()) {
    attachAndHomeAll();
    controllerState = STARTING_ONE_SHOT;
    startingSince = millis();
    Serial.println(F("[FOLD] Returning all plates home before one-shot sequence."));
    return;
  }

  controllerState = RUNNING_ONE_SHOT;
  Serial.println(F("FOLDING"));
  Serial.println(F("[FOLD] START one-shot sequence."));
}


// ------------------------------------------------------------
// e4 addition: synchronized G scenario
// ------------------------------------------------------------
int syncRatioAngle(int servoIndex, float ratio) {
  ratio = constrain(ratio, 0.0f, 1.0f);
  return (int)round(
    startAngles[servoIndex] +
    (operateAngles[servoIndex] - startAngles[servoIndex]) * ratio
  );
}

void syncSetPlateTarget(
  int targets[SERVO_COUNT],
  int plateIndex,
  float ratio
) {
  int servoA = plateServoA[plateIndex];
  int servoB = plateServoB[plateIndex];

  targets[servoA] = syncRatioAngle(servoA, ratio);
  if (servoB >= 0) {
    targets[servoB] = syncRatioAngle(servoB, ratio);
  }
}

bool syncMoveToTargets(
  const int targets[SERVO_COUNT],
  ControllerState requiredState
) {
  int from[SERVO_COUNT];
  int maxDistance = 0;

  for (int i = 0; i < SERVO_COUNT; i++) {
    from[i] = currentAngles[i];
    maxDistance = max(maxDistance, abs(targets[i] - from[i]));
  }

  if (maxDistance == 0) {
    return true;
  }

  int totalSteps =
    (maxDistance + SYNC_STEP_DEGREES - 1) /
    SYNC_STEP_DEGREES;

  for (int step = 1; step <= totalSteps; step++) {
    for (int i = 0; i < SERVO_COUNT; i++) {
      int nextAngle =
        from[i] +
        ((long)(targets[i] - from[i]) * step) /
        totalSteps;

      servos[i].write(nextAngle);
      currentAngles[i] = nextAngle;
    }

    if (!waitWhileState(SYNC_STEP_DELAY_MS, requiredState)) {
      return false;
    }
  }

  for (int i = 0; i < SERVO_COUNT; i++) {
    servos[i].write(targets[i]);
    currentAngles[i] = targets[i];
  }

  return true;
}

bool syncMoveRatios(
  float p1,
  float p2,
  float p3,
  float p4,
  float p5,
  ControllerState requiredState
) {
  float ratios[PLATE_COUNT] = {p1, p2, p3, p4, p5};
  int targets[SERVO_COUNT];

  for (int i = 0; i < SERVO_COUNT; i++) {
    targets[i] = currentAngles[i];
  }

  for (int plate = 0; plate < PLATE_COUNT; plate++) {
    syncSetPlateTarget(targets, plate, ratios[plate]);
  }

  return syncMoveToTargets(targets, requiredState);
}
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

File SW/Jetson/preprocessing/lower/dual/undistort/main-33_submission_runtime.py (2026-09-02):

from __future__ import annotations
import argparse
import copy
import dataclasses
import hashlib
import importlib
import importlib.util
import json
import math
import os
from pathlib import Path
import select
import shutil
import subprocess
import sys
import threading
import time
from types import ModuleType, SimpleNamespace
from typing import Any, Dict, Iterable, List, Optional, Sequence, Tuple
import numpy as np
SCHEMA_VERSION = 6
MOTION_VERSION = 'bottom_vla_manual_merged_v20_main33'
MOTION_POLICY_VERSION = 'main-33_d56-real-fix55-fix56-2d-master_fix59-grip_d58-strongest-safe-correction'
D56_RECOGNITION_VERSION = 'd56-45_pose_mask_waist_semantic_hardening'
D54_D55_EXTRA_GRIP_INSET_MM = 15.0
D55_EXTRA_GRIP_INSET_MM = 25.0
D54_PULL_GAIN = 0.85
D54_PULL_MIN_MM = 110.0
D54_PULL_MAX_MM = 180.0
D54_PULL_HARD_MAX_MM = 200.0
D54_PULL_EXTRA_MM = 50.0
D56_TEMPORAL_FRAMES = 1
D56_TEMPORAL_INTERVAL_S = 0.12
MAIN28_D56_TAUGHT_PROFILE = ((0.0, -0.0, 0.0), (0.243636, -3.92154, -0.000892114), (0.487273, -4.55104, -0.00179596), (0.730909, -6.168245, -0.001844065), (0.974545, -21.5546, -7.585e-06), (1.21818, -39.0347, -5.5918e-05), (1.46182, -56.3596, -5.3164e-05), (1.70545, -76.97455, 0.000986806), (1.94909, -96.92435, 0.00298452), (2.19273, -115.5395, 0.01320717), (2.43636, -134.473, 0.00143447), (2.68, -150.1875, -0.0016798), (2.92364, -175.905, 0.007579168), (3.16727, -203.117, 0.00285499), (3.41091, -235.9875, 0.032011865), (3.65455, -255.731, 0.0393463), (3.89818, -271.941, 0.06006345), (4.14182, -285.7525, 0.09057645), (4.38545, -292.5265, 0.1095675), (4.62909, -293.9055, 0.112792), (4.87273, -294.253, 0.113179), (5.11636, -294.5935, 0.1131135), (5.36, -299.59, 0.114407), (5.60364, -305.0085, 0.1145715), (5.84727, -307.7095, 0.116884), (6.09091, -308.013, 0.1182975), (6.33455, -308.383, 0.1181905), (6.57818, -308.3325, 0.116033), (6.82182, -308.588, 0.1163925), (7.06545, -308.549, 0.116129), (7.30909, -307.473, 0.1118825), (7.55273, -305.8175, 0.1074725), (7.79636, -305.108, 0.1076285), (8.04, -302.1405, 0.10158865), (8.28364, -298.2655, 0.1001026), (8.52727, -292.083, 0.107656), (8.77091, -277.273, 0.1075448), (9.01455, -258.9865, 0.114655), (9.25818, -233.308, 0.113466), (9.50182, -195.5675, 0.118603), (9.74545, -149.48, 0.1423935), (9.98909, -88.40565, 0.1875995), (10.2327, -29.3386, 0.2556565), (10.4764, 23.4986, 0.3441795), (10.72, 71.43995, 0.4198805), (10.9636, 112.655, 0.516758), (11.2073, 156.4215, 0.5957665), (11.4509, 190.823, 0.69197), (11.6945, 225.1915, 0.7842095), (11.9382, 258.2475, 0.8651335), (12.1818, 281.745, 0.9348375), (12.4255, 294.818, 0.9739865), (12.6691, 296.7195, 0.9978155), (12.9127, 302.844, 0.995617), (13.1564, 303.2365, 0.9995825), (13.4, 303.0955, 1.0))
MAIN28_D56_TAUGHT_PROFILE_SHA16 = '2645f613bc21f1a5'
MAIN28_D56_SOURCE_DURATION_S = 13.4
MAIN28_D56_SOURCE_BACK_MM = 308.588
MAIN28_D56_SOURCE_FORWARD_MM = 303.2365
MAIN33_D56_SOURCE_SHA256 = '8345bd50917eb3de51711994c462cc10bf13a532040fde7ca55642d9360f66fa'
MAIN33_D56_CANONICAL_LOCAL = {'arm1': (246.1141701, 28.1145506, 338.7358978), 'arm2': (257.3242225, -36.155616, 319.4688398)}
MAIN33_D56_SOURCE_TRAJECTORY = ((0.0, 0.0, 0.0, 0.0, 0.0, 0.0, 0.0), (0.243636, -0.113793, -3.75542, -0.000803518, 0.0471378, 4.08766, -0.00098071), (0.487273, -0.77219, -4.34194, -0.00261121, 0.130048, 4.76014, -0.00098071), (0.730909, -0.604324, -6.22098, -0.00270742, 0.2983, 6.11551, -0.00098071), (0.974545, 2.39755, -20.3291, 0.00096554, 1.70576, 22.7801, -0.00098071), (1.21818, 2.24101, -38.4607, 0.000868874, 2.0008, 39.6087, -0.00098071), (1.46182, 1.0853, -54.2023, 0.000874382, 1.06638, 58.5169, -0.00098071), (1.70545, -1.03598, -75.5446, 0.0026784, -1.27111, 78.4045, -0.000704789), (1.94909, -5.49367, -94.7303, 0.00278768, -3.61108, 99.1184, 0.00318136), (2.19273, -1.65627, -113.287, 0.0189248, -6.74667, 117.792, 0.00748954), (2.43636, 13.6354, -134.914, -0.00501128, -12.4153, 134.032, 0.00788022), (2.68, 16.6481, -143.286, -0.0134658, -21.7795, 157.089, 0.0101062), (2.92364, 6.13851, -175.831, -0.000541164, -19.5156, 175.979, 0.0156995), (3.16727, 1.43376, -197.647, 0.0123114, -0.375874, 208.587, -0.00660142), (3.41091, 0.897959, -233.088, 0.0548157, -6.84229, 238.887, 0.00920803), (3.65455, 9.8432, -257.638, 0.0605592, -17.5511, 253.824, 0.0181334), (3.89818, 12.6047, -270.08, 0.0697406, -18.9339, 273.802, 0.0503863), (4.14182, 8.53176, -278.197, 0.0817431, -11.8823, 293.308, 0.0994098), (4.38545, 15.7941, -291.024, 0.116166, -11.0532, 294.029, 0.102969), (4.62909, 14.7719, -293.344, 0.119962, -10.635, 294.467, 0.105622), (4.87273, 14.5134, -293.584, 0.119876, -10.7166, 294.922, 0.106482), (5.11636, 14.3011, -293.793, 0.119876, -11.2478, 295.394, 0.106351), (5.36, 12.7333, -295.304, 0.119792, -19.6774, 303.876, 0.109022), (5.60364, 1.62705, -305.975, 0.122021, -20.3239, 304.042, 0.107122), (5.84727, 1.98838, -306.109, 0.125166, -26.0197, 309.31, 0.108602), (6.09091, 2.17505, -306.318, 0.127767, -26.4709, 309.708, 0.108828), (6.33455, 2.07473, -306.206, 0.126373, -26.4825, 310.56, 0.110008), (6.57818, 1.695, -305.78, 0.121283, -26.1598, 310.885, 0.110783), (6.82182, 1.84687, -305.95, 0.120564, -25.8729, 311.226, 0.112221), (7.06545, 1.82422, -305.925, 0.120258, -25.9171, 311.173, 0.112), (7.30909, 0.625154, -304.582, 0.114797, -26.4186, 310.364, 0.108968), (7.55273, -0.152674, -302.995, 0.111562, -27.0949, 308.64, 0.103383), (7.79636, -0.123968, -302.737, 0.114609, -27.317, 307.479, 0.100648), (8.04, -1.39131, -298.175, 0.103971, -26.4857, 306.106, 0.0992063), (8.28364, -4.1678, -291.051, 0.0965352, -25.7553, 305.48, 0.10367), (8.52727, -13.631, -279.859, 0.111109, -25.833, 304.307, 0.104203), (8.77091, -23.7403, -268.226, 0.126812, -19.5774, 286.32, 0.0882776), (9.01455, -22.8117, -257.714, 0.12432, -33.6441, 260.259, 0.10499), (9.25818, -16.3989, -228.703, 0.121583, -32.6031, 237.913, 0.105349), (9.50182, -35.0878, -189.799, 0.136493, -25.6784, 201.336, 0.100713), (9.74545, -31.0159, -145.533, 0.153439, -30.6861, 153.427, 0.131348), (9.98909, -34.0764, -82.4938, 0.204064, -27.5938, 94.3175, 0.171135), (10.2327, -34.7935, -24.2842, 0.267999, -23.4123, 34.393, 0.243314), (10.4764, -43.7734, 30.2581, 0.356526, -30.4645, -16.7391, 0.331833), (10.72, -51.2346, 79.4929, 0.441814, -38.2522, -63.387, 0.397947), (10.9636, -52.0062, 121.989, 0.526172, -31.5926, -103.321, 0.507344), (11.2073, -48.5363, 165.967, 0.60677, -33.4364, -146.876, 0.584763), (11.4509, -35.005, 204.914, 0.69343, -44.9401, -176.732, 0.69051), (11.6945, -35.6794, 237.469, 0.783072, -37.9573, -212.914, 0.785347), (11.9382, -39.2221, 267.704, 0.85401, -33.5211, -248.791, 0.876257), (12.1818, -44.4132, 289.596, 0.919927, -26.1592, -273.894, 0.949748), (12.4255, -53.1687, 302.099, 0.955227, -22.2905, -287.537, 0.992746), (12.6691, -55.2485, 302.811, 0.986981, -21.4951, -290.628, 1.00865), (12.9127, -53.2343, 307.641, 0.991054, -21.4554, -298.047, 1.00018), (13.1564, -53.4845, 307.111, 0.999914, -22.6181, -299.362, 0.999251), (13.4, -53.4886,
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

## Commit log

2026-08-31 Add README for Jetson Orin Nano software
2026-08-31 Create camera
2026-09-01 Add upper-garment Jetson runtime
2026-09-01 Add lower-garment Jetson runtime
2026-09-02 Correct typo in README for Dual Robot Arm
2026-09-02 Remove redundant App Arduino and docs READMEs
2026-09-02 Restore App and Arduino directories
2026-09-02 Add folding board Arduino servo controller
2026-09-02 Revise README.md for clarity and consistency
    Updated README.md to enhance clarity and consistency in descriptions. Changed terminology from 'Full-Auto Manipulation Runtime' to '완전 자동 조작 Runtime' and improved various phrases for better understan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
2026-09-02 Update Jetson README for current upper and lower automation
2026-09-02 Update common README for camera controls
